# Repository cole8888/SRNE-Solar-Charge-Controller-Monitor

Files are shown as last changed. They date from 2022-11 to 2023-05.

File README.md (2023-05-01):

# SRNE-Solar-Charge-Controller-Monitor

Read data from SRNE solar charge controllers via modbus over RS232.

This repository contains several example programs for reading data from SRNE solar charge controllers using Raspberry Pi, ESP32, ESP8266 and Arduino Nano / Uno.

Based on the modbus manuals, this should also work with some Renogy controllers, but I don't have one to test with. Also, verify the wiring is compatible with your controller.

<hr>

## Example Setups:

Here are some example programs to get started. If you follow the setup instructions in the readme files of each directory, you should be able to talk to your controller. If you are just getting started, don't use the MQTT ones.

### [Raspberry Pi](./RaspberryPi-Examples/)

### [ESP32](./ESP32-Examples/)

### [ESP8266](./ESP8266-Examples/)

### [Arduino Nano / Uno](./Arduino-Example/)

<hr>

## Web-Interface and MQTT

I've included an [example web interface](./Web-Interface-Example/) you can use in combination with the MQTT-enabled example programs. To use it, you will need to setup an MQTT broker such as [Mosquitto](https://github.com/eclipse/mosquitto) or use a cloud broker. You will also need to set all the appropriate settings in the chosen program and the [index.js](./Web-Interface-Example/index.js) file.

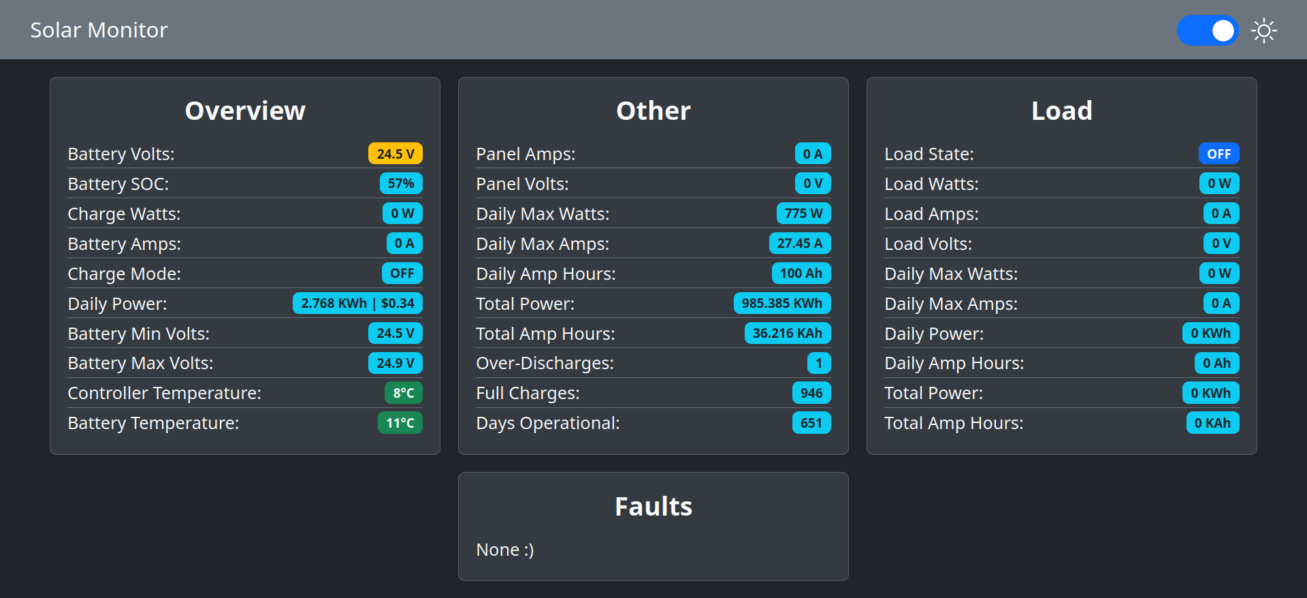
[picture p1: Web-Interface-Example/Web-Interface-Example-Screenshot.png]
Web-Interface-Screenshot


I also included my [custom web interface](./My-Current-Setup/Web-Interface/) which I am using for my setup. It has the ability to read data from and control smart plugs flashed with Tasmota.

<hr>

## My Current Setup:

The setup I use is a customized version of the ESP32 Example, I also designed a custom PCB. Have a look at [My-Current-Setup](./My-Current-Setup) if you want some inspiration for your own setup!

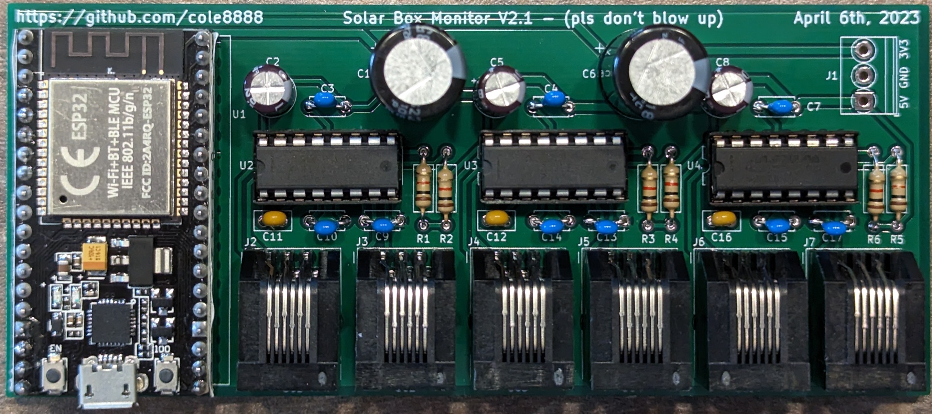
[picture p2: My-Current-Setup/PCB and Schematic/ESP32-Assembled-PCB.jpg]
ESP32 PCB Image


<hr>

## Troubleshooting:

If you notice lots of timeouts, or other errors, try some these steps before creating an issue:

- Try a different power supply and USB cable. My ML2440 does not respond when I use one of my USB power bricks, but it does with another.
- Try increasing the modbus timeout value.
- Try using a shorter cables and moving them away from interference.
- Verify you are using straight cables and not ones that reverse from one end to the other.
- Try using HardwareSerial instead of SoftwareSerial. I've found HardwareSerial is more reliable, configure the program to use it if you are having problems.

<b>If these don't help or if you need clarification, feel free to create an issue and I'll see what I can do!</b>

<hr>

## Other notes:

- I've included the [SRNE modbus manual](./SRNE-MODBUS.pdf) if you want to have a look at it. My examples read all the registers I think are important, but there are lots of other registers which I haven't touched. Be careful, some of them can be written to!

- The Python version was originally based on: http://vcsco.com/uncategorized/renogy-rover-monitoring-with-the-raspberry-pi/

- The Web-Interface was originally based on: https://github.com/fabaff/mqtt-panel

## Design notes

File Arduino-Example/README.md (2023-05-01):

# Arduino Version

This is an example sketch which uses an Arduino nano and can be adapted to an Arduino Uno. Once you get this working and want to have a go at doing more with the data, have a look at [my setup](../My-Current-Setup/) for inspiration!

Please note that there is no MQTT-enabled Arduino version as these boards have no integrated way of communicating the data over the network like the RaspberryPi and ESP modules do.

## Libraries

The libraries this project uses are:

- https://github.com/4-20ma/ModbusMaster
- https://github.com/bblanchon/ArduinoJson

## Hardware

- 1 x Arduino Nano or Arduino Uno
- 1 x RS232 transceiver module. Ex: [MAX3232 Module](https://www.digikey.ca/en/products/detail/mikroelektronika/MIKROE-602/4495610)
- 1 x [6P6C Straight Cable](https://www.digikey.ca/en/products/detail/assmann-wsw-components/AT-S-26-6-6-B-7-R/1972588) (Double check wire colors against [6P6C-Connector.jpg](../6P6C-Connector.jpg))

## Wiring

See the schematic or other photos in this directory for details.
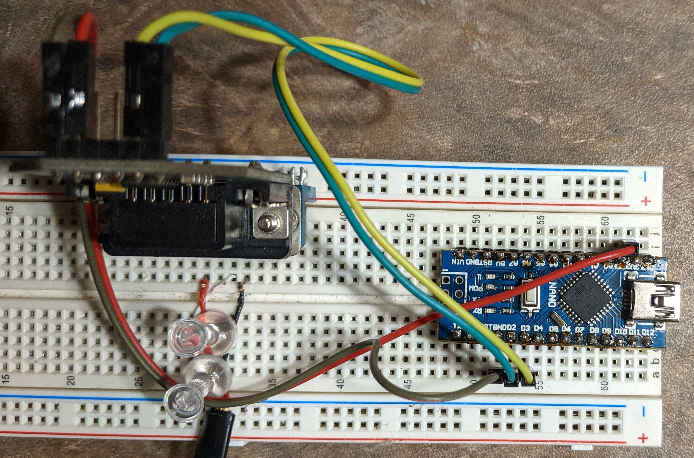
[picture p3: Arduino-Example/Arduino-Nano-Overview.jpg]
Arduino Nano Overview


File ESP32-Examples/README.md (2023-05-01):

# ESP32 Example

This is an example sketch which connects to a single charge controller so you can get started easily. Once you get this working and want to have a go at doing more with the data, have a look at [my setup](../My-Current-Setup/) for inspiration!

## Libraries

The libraries this project uses are:

- https://github.com/4-20ma/ModbusMaster
- https://github.com/bblanchon/ArduinoJson
- https://github.com/knolleary/pubsubclient (MQTT Example)

## Hardware:

- 1 x ESP32 DevKit Module
- 1 x RS232 transceiver module. Ex: [MAX3232 Module](https://www.digikey.ca/en/products/detail/mikroelektronika/MIKROE-602/4495610)
- 1 x [6P6C Straight Cable](https://www.digikey.ca/en/products/detail/assmann-wsw-components/AT-S-26-6-6-B-7-R/1972588) (Double check wire colors against [6P6C-Connector.jpg](../6P6C-Connector.jpg))

## Wiring:

Additional perspectives in the other pictures in this directory.

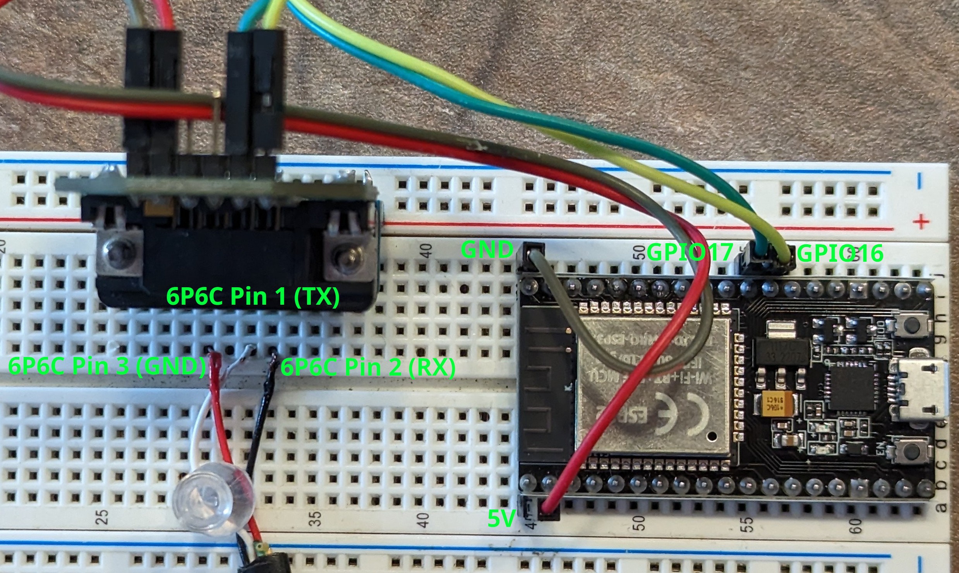
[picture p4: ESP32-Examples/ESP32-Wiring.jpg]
Wiring


## PCB

I designed a PCB which uses an ESP32 and can handle up to 6 charge controllers at once.
Have a look at it [here](../My-Current-Setup/).

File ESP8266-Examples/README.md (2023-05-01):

# ESP8266 Example
This is an example sketch which uses an ESP8266. Once you get this working and want to have a go at doing more with the data, have a look at [my setup](../My-Current-Setup/) for inspiration!

## Libraries
The libraries this project uses are:
- https://github.com/4-20ma/ModbusMaster
- https://github.com/bblanchon/ArduinoJson
- https://github.com/knolleary/pubsubclient (MQTT Example)

## Hardware:
- 1 x ESP8266 Module
- 1 x RS232 transceiver module. Ex: [MAX3232 Module](https://www.digikey.ca/en/products/detail/mikroelektronika/MIKROE-602/4495610)
- 1 x [6P6C Straight Cable](https://www.digikey.ca/en/products/detail/assmann-wsw-components/AT-S-26-6-6-B-7-R/1972588) (Double check wire colors against [6P6C-Connector.jpg](../6P6C-Connector.jpg))

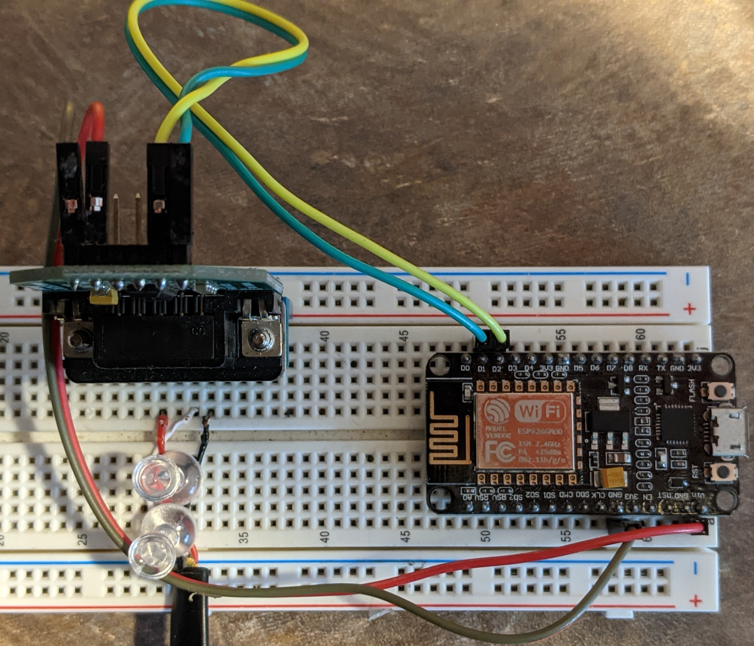
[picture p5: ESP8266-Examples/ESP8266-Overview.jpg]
ESP8266 Overview


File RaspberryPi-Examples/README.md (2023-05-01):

# Raspberry Pi Version
This example fetches the data from the controller and prints it to the console. You have the option to print it out in a text or json format.

If you encounter any issues, create an issue and I'll try to help.

## Setup:
You will need to enable serial on the raspberry pi, I used this guide: https://pimylifeup.com/raspberry-pi-serial/

You may also need to switch the serial device depending on what Pi or other device you are using.

## Libraries
- [pymodbus](https://github.com/pymodbus-dev/pymodbus)
- [paho-mqtt](https://pypi.org/project/paho-mqtt/) (Only for MQTT version)

## Hardware:
- 1 x Raspberry Pi
- 1 x RS232 transceiver module. Ex: [MAX3232 Module](https://www.digikey.ca/en/products/detail/mikroelektronika/MIKROE-602/4495610)
- 1 x [6P6C (RJ12) Straight Cable](https://www.digikey.ca/en/products/detail/assmann-wsw-components/AT-S-26-6-6-B-7-R/1972588) (Double check wire colors against [6P6C-Connector.jpg](../6P6C-Connector.jpg))

## Wiring
See other pictures for different perspectives.
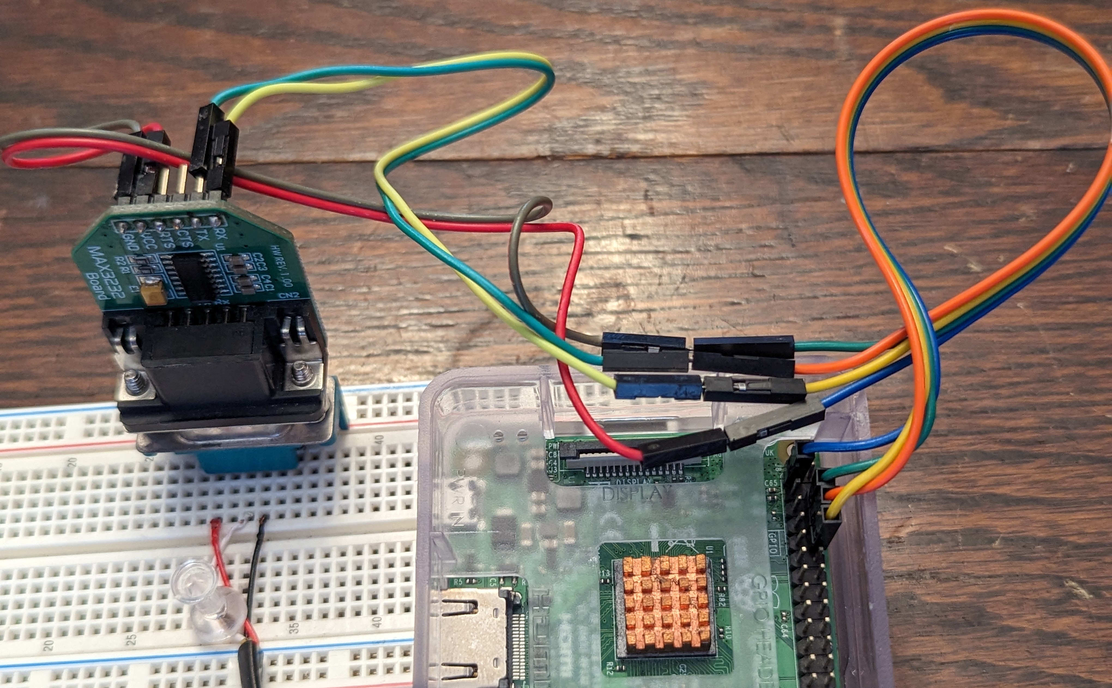
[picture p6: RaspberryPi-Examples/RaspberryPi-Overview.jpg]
RaspberryPi-Overview


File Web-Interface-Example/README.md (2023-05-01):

# Web Interface Example

This is an example web interface for viewing data returned by the example programs which publish to MQTT.

Since each of the MQTT-enabled example programs publish the data using the same JSON format, they should work out of the box assuming you specify the MQTT broker settings.



To use the interface you will need to open [index.js](./index.js) and specify the address and port of your MQTT broker along with any credentials.

This uses websockets to get the MQTT data to the browser. When configuring your broker you may need to set those up and have them run on a different port than the rest of the MQTT traffic.

<hr>

Originally based on https://github.com/fabaff/mqtt-panel

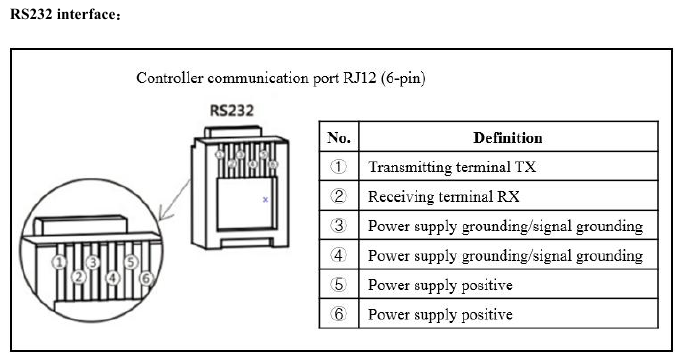
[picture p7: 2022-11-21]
Charge-Controller-Connector-Pinout.png

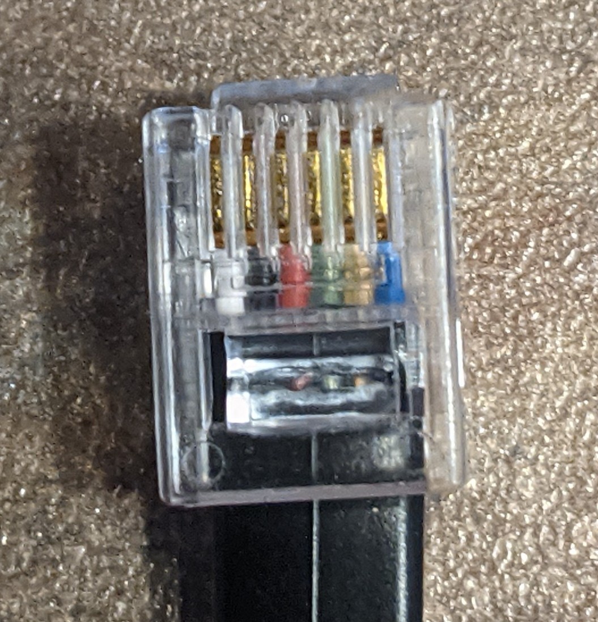
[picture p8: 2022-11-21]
6P6C-Connector.jpg

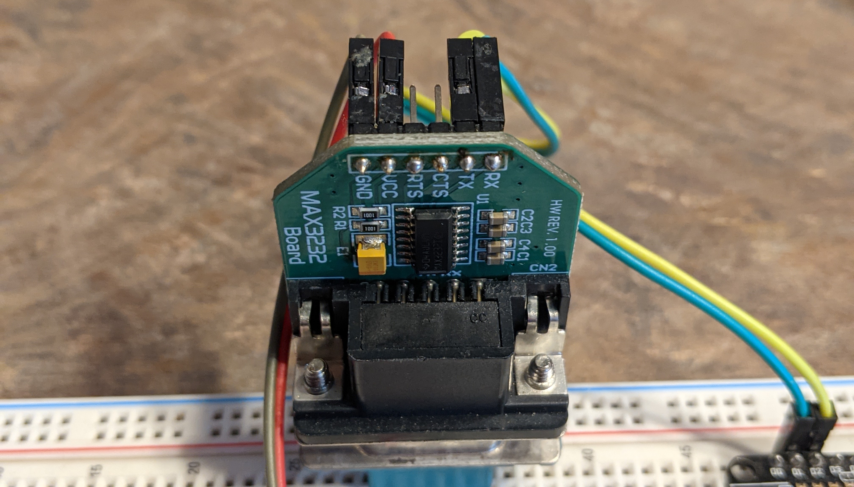
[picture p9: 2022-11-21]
Arduino-Example/MAX3232-Closeup.jpg

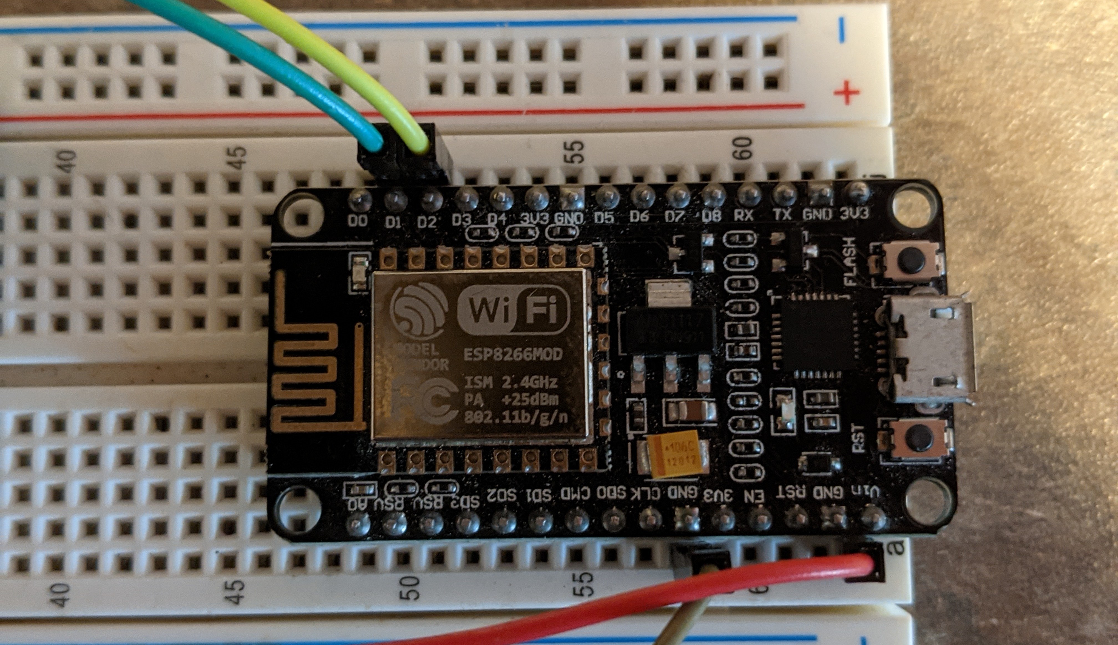
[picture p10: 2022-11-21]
ESP8266-Examples/ESP8266-Closeup.jpg

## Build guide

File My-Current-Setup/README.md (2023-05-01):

# My-Current-Setup

This is the setup I currently use. Feel free to use it for inspiration!

This version isn't intended to be plug and play like the other examples as it is specific to my needs.

## Layout

I have 3 solar charge controllers, one for the front, side, and back arrays. They feed into the ESP32 which collects the data and publishes it to an MQTT server that clients (such as the web-ui) can connect to.

I also have an ESP8266 with an LCD attached that subscribes to the MQTT feed to display some data in a convenient location around the house.

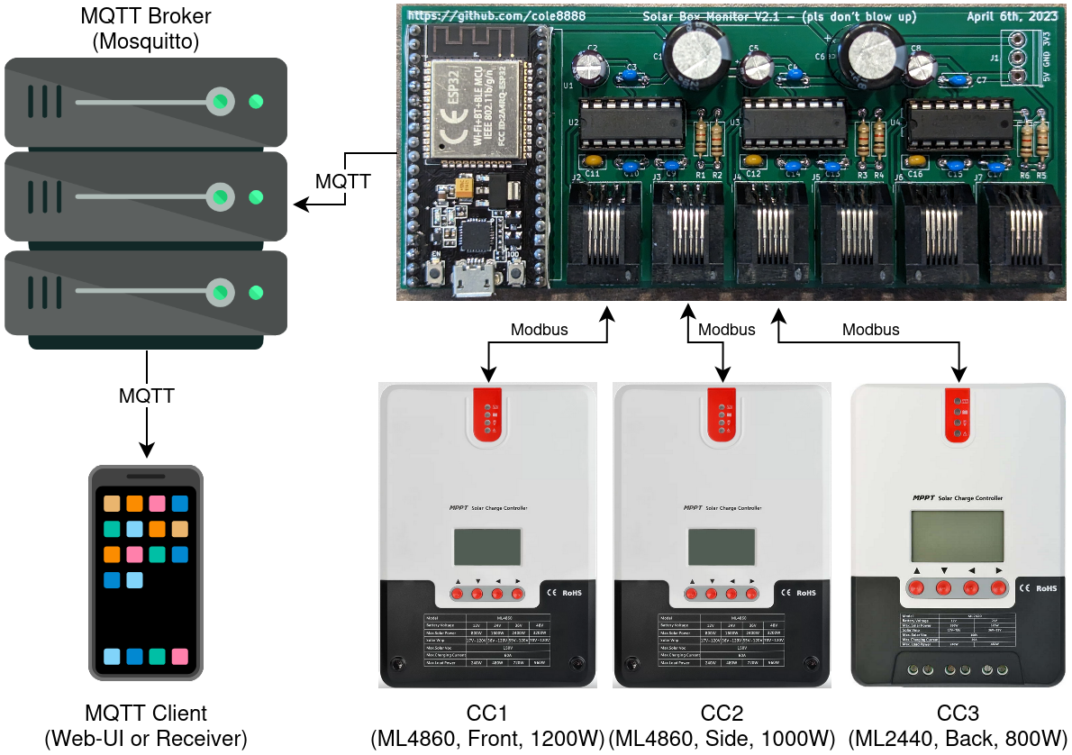
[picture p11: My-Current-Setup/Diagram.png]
Diagram


## Libraries

The libraries this project uses are:

- https://github.com/4-20ma/ModbusMaster
- https://github.com/bblanchon/ArduinoJson
- https://github.com/knolleary/pubsubclient
- https://github.com/plerup/espsoftwareserial/ (Optional, needed for >2 controllers)
- https://github.com/ayushsharma82/AsyncElegantOTA (Optional, Over the air updates)
- https://github.com/ayushsharma82/WebSerial (Optional, Over the air debugging)
- https://github.com/me-no-dev/ESPAsyncWebServer/ (Dependency of OTA and WebSerial)
- https://github.com/me-no-dev/AsyncTCP/ (Dependency of OTA and WebSerial)
- https://github.com/fdebrabander/Arduino-LiquidCrystal-I2C-library (Optional, for receiver)

## Hardware

### PCB

I designed a custom PCB for this, have a look at the [PCB files and schematic](./PCB%20and%20Schematic/).

Each PCB can handle up to 6 charge controllers at once!

PCB

NOTE: If you do plan to use my PCB, make sure you verify the footprint of the ESP32 you plan to use. The ones I have are a bit narrower than most, so you may need to adjust the footprint.

### Components:

This list is for a fully populated PCB, you may not need everything here, see schematic for details.

- 1 x [ESP32 DevKit Narrow](https://www.amazon.ca/gp/product/B07QCP2451/) (Unless you adjusted the PCB footprint yourself)
- 3 x [MAX3232](https://www.digikey.ca/en/products/detail/analog-devices-inc-maxim-integrated/MAX3232EEPE/1512691) (Or equivalent)
- 3 x [10uF Capacitor](https://www.digikey.ca/en/products/detail/nichicon/ULD2A100MED1TD/7365013)
- 9 x [0.47uF Capacitor](https://www.digikey.ca/en/products/detail/tdk-corporation/FG28X7R1H474KRT06/5803214)
- 3 x [0.1uF Capacitor](https://www.digikey.ca/en/products/detail/vishay-beyschlag-draloric-bc-components/K104K15X7RF5TL2/286538)
- 6 x [1kOhm Resistor](https://www.digikey.ca/en/products/detail/stackpole-electronics-inc/CF14JT1K00/1741314)
- 6 x [6P6C Jack](https://www.digikey.ca/en/products/detail/amphenol-cs-commercial-products/RJE031660110/4889694)
- 6 x [6P6C Straight Cable](https://www.digikey.ca/en/products/detail/assmann-wsw-components/AT-S-26-6-6-B-7-R/1972588)
- 2 x [1000uF Capacitor](https://www.digikey.ca/en/products/detail/rubycon/35ZLH1000MEFC12-5X20/3564067) (Recommended)
- 2 x [19 Position Female Header](https://www.digikey.ca/en/products/detail/sullins-connector-solutions/PPTC191LFBN-RC/810157) (Recommended, for ESP32)
- 3 x [16 Pin Dip Socket](https://www.digikey.ca/en/products/detail/amphenol-cs-fci/DILB16P-223TLF/4292068) (Recommended, for MAX3232)
- 1 x [3 position screw terminal](https://www.digikey.ca/en/products/detail/phoenix-contact/1984620/950850) (Optional)

## Web Interface

This is a customized version of the [example web interface](../Web-Interface-Example/). It has a different layout since I needed to display data from 3 charge controllers while also having smart plug controls.

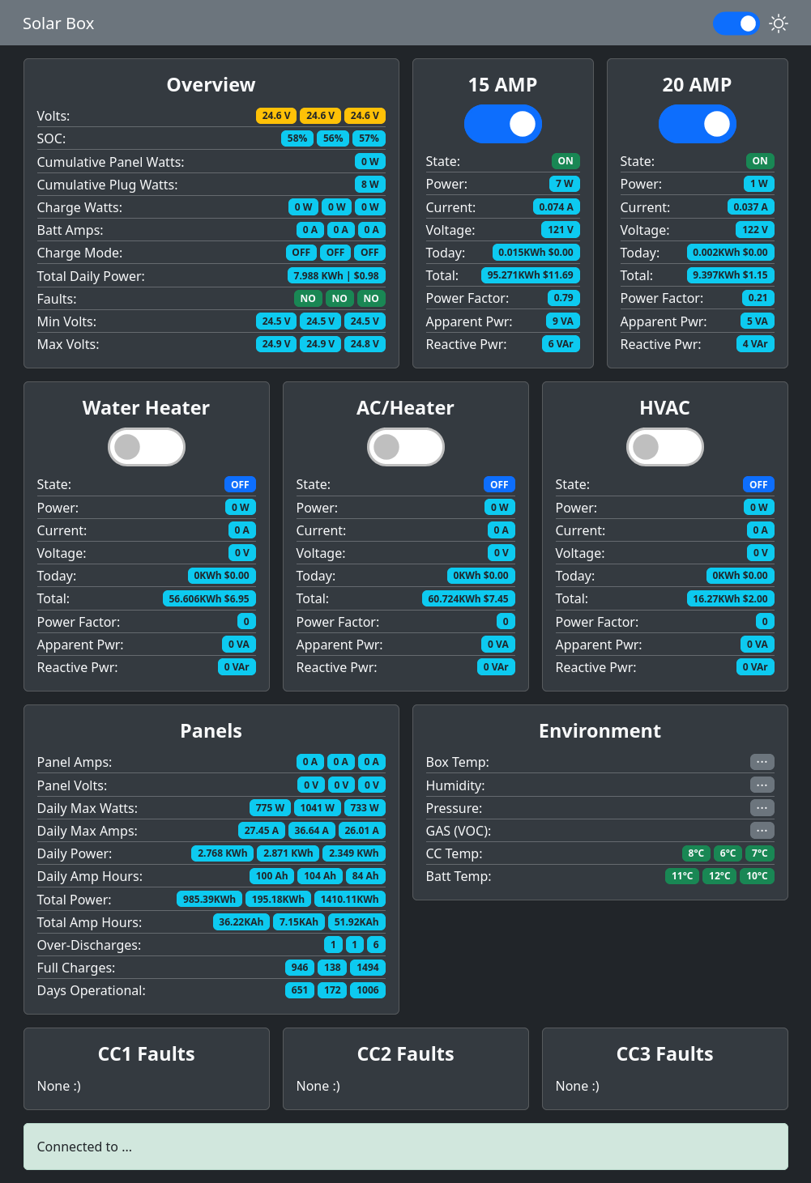
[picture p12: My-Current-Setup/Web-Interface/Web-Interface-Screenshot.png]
Web-Interface-Screenshot


<hr>

- The Web interface was originally based on https://github.com/fabaff/mqtt-panel
- Server icon in diagram is from [Roundicons](https://www.flaticon.com/free-icons/server).

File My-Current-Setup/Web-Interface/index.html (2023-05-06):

#### Overview

###### Volts: ⋅⋅⋅ ⋅⋅⋅ ⋅⋅⋅

###### SOC: ⋅⋅⋅ ⋅⋅⋅ ⋅⋅⋅

###### Cumulative Panel Watts: ⋅⋅⋅

###### Cumulative Plug Watts: ⋅⋅⋅

###### Charge Watts: ⋅⋅⋅ ⋅⋅⋅ ⋅⋅⋅

###### Batt Amps: ⋅⋅⋅ ⋅⋅⋅ ⋅⋅⋅

###### Charge Mode: ⋅⋅⋅ ⋅⋅⋅ ⋅⋅⋅

###### Total Daily Power: ⋅⋅⋅

###### Faults: ⋅⋅⋅ ⋅⋅⋅ ⋅⋅⋅

###### Min Volts: ⋅⋅⋅ ⋅⋅⋅ ⋅⋅⋅

###### Max Volts: ⋅⋅⋅ ⋅⋅⋅ ⋅⋅⋅

#### 15 AMP (http://192.168.2.131)

# Are you sure?

Are you sure you want to turn off the 15 AMP Plug?

Cancel Yes

###### State:⋅⋅⋅

###### Power: ⋅⋅⋅

###### Current: ⋅⋅⋅

###### Voltage: ⋅⋅⋅

###### Today: ⋅⋅⋅

###### Total: ⋅⋅⋅

###### Power Factor: ⋅⋅⋅

###### Apparent Pwr: ⋅⋅⋅

###### Reactive Pwr: ⋅⋅⋅

#### 20 AMP (http://192.168.2.107)

# Are you sure?

Are you sure you want to turn off the 20 AMP Plug?

Cancel Yes

###### State:⋅⋅⋅

###### Power: ⋅⋅⋅

###### Current: ⋅⋅⋅

###### Voltage: ⋅⋅⋅

###### Today: ⋅⋅⋅

###### Total: ⋅⋅⋅

###### Power Factor: ⋅⋅⋅

###### Apparent Pwr: ⋅⋅⋅

###### Reactive Pwr: ⋅⋅⋅

#### Water Heater (http://192.168.2.118)

###### State:⋅⋅⋅

###### Power: ⋅⋅⋅

###### Current: ⋅⋅⋅

###### Voltage: ⋅⋅⋅

###### Today: ⋅⋅⋅

###### Total: ⋅⋅⋅

###### Power Factor: ⋅⋅⋅

###### Apparent Pwr: ⋅⋅⋅

###### Reactive Pwr: ⋅⋅⋅

#### AC/Heater (http://192.168.2.119)

###### State:⋅⋅⋅

###### Power: ⋅⋅⋅

###### Current: ⋅⋅⋅

###### Voltage: ⋅⋅⋅

###### Today: ⋅⋅⋅

###### Total: ⋅⋅⋅

###### Power Factor: ⋅⋅⋅

###### Apparent Pwr: ⋅⋅⋅

###### Reactive Pwr: ⋅⋅⋅

#### HVAC (http://192.168.2.176)

###### State:⋅⋅⋅

###### Power: ⋅⋅⋅

###### Current: ⋅⋅⋅

###### Voltage: ⋅⋅⋅

###### Today: ⋅⋅⋅

###### Total: ⋅⋅⋅

###### Power Factor: ⋅⋅⋅

###### Apparent Pwr: ⋅⋅⋅

###### Reactive Pwr: ⋅⋅⋅

#### Panels

###### Panel Amps: ⋅⋅⋅ ⋅⋅⋅ ⋅⋅⋅

###### Panel Volts: ⋅⋅⋅ ⋅⋅⋅ ⋅⋅⋅

###### Daily Max Watts: ⋅⋅⋅ ⋅⋅⋅ ⋅⋅⋅

###### Daily Max Amps: ⋅⋅⋅ ⋅⋅⋅ ⋅⋅⋅

###### Daily Power: ⋅⋅⋅ ⋅⋅⋅ ⋅⋅⋅

###### Daily Amp Hours: ⋅⋅⋅ ⋅⋅⋅ ⋅⋅⋅

###### Total Power: ⋅⋅⋅ ⋅⋅⋅ ⋅⋅⋅

###### Total Amp Hours: ⋅⋅⋅ ⋅⋅⋅ ⋅⋅⋅

###### Over-Discharges: ⋅⋅⋅ ⋅⋅⋅ ⋅⋅⋅

###### Full Charges: ⋅⋅⋅ ⋅⋅⋅ ⋅⋅⋅

###### Days Operational: ⋅⋅⋅ ⋅⋅⋅ ⋅⋅⋅

#### Environment

###### Box Temp: ⋅⋅⋅

###### Humidity: ⋅⋅⋅

###### Pressure: ⋅⋅⋅

###### GAS (VOC): ⋅⋅⋅

###### CC Temp: ⋅⋅⋅ ⋅⋅⋅ ⋅⋅⋅

###### Batt Temp: ⋅⋅⋅ ⋅⋅⋅ ⋅⋅⋅

#### CC1 Faults

###### None :)

#### CC2 Faults

###### None :)

#### CC3 Faults

###### None :)

Loading...

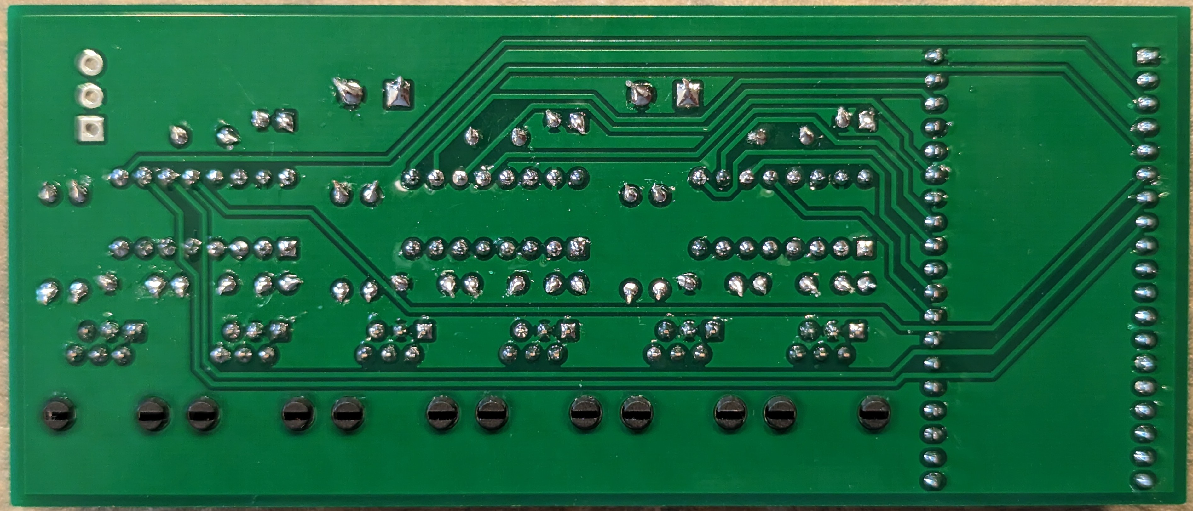
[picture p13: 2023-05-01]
My-Current-Setup/PCB and Schematic/ESP32-Assembled-PCB-Back.jpg

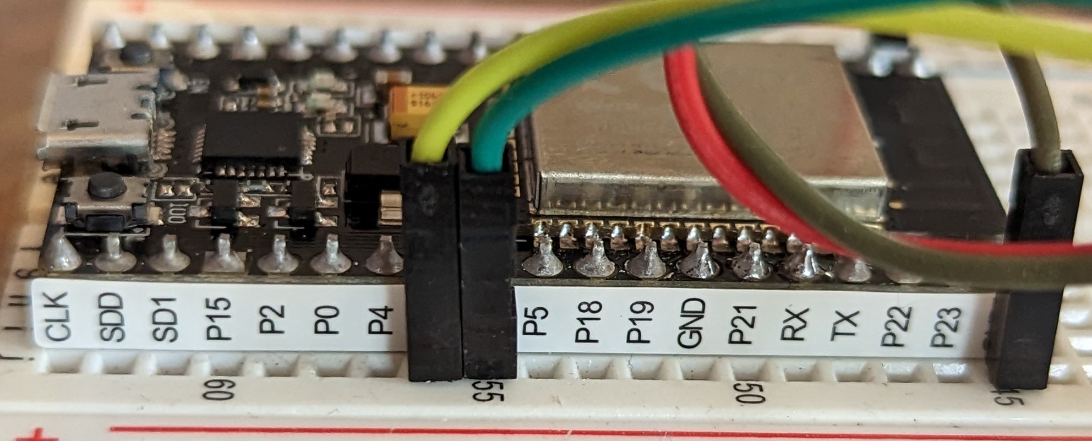
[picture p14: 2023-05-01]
ESP32-Examples/ESP32-Wiring-Side.jpg

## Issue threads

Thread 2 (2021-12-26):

<0°C temperatures dont work.

cole8888, 2021-12-26:
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

Something is wonky with the temperature readouts when the temperature gets to <0.

Was not able to test this at the time I wrote this program because it was summer time.

I have only checked the Arduino version, I'm not sure if the python version also has this problem, but I assume it does.

Closed 2022-10-08.

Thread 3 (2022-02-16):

[QUESTION]

curiousIya, 2022-02-16:
Hi! Thank you so much for your python code :) I'm using it to read my ML4860 Solar Controller.
I removed the mqtt and the CC1 lines.

Just some questions,
How do you know how many registers to read?
And which registers refers to a value (eg r.registers[7] is Panel Voltage)?
Also, whose temperature do you refer in CPUTemperature().temperature? the raspberry pi?

cole8888, 2022-02-16:
You can determine which register corresponds to which value using the modbus manual I included here: https://github.com/cole8888/SRNE-Solar-Charge-Controller-Monitor/blob/main/srne_modbus_protocol-_3.8-english.pdf

For instance, at the start of the "Controller dynamic information" section you can see 0100H (100 in hexadecimal, 256 in decimal) is the battery state of charge percentage.

As for the number of registers, the reason I read 34 registers in my code is because that is the end of the "Controller dynamic information" section (122H) and beyond this address you start getting into the memory for the controller settings, which I was not interested in.

So if you only ever wanted to read the battery state of charge percentage and the battery voltage and nothing else, you could change that 34 to 2 since you'd only need to be reading registers 100H and 101H. If I were you I'd leave it at 34 though since that way it returns all the information you could possibly need.

Also, yes the CPU temperature was for the raspberry pi. The deck box I use can get pretty toasty and I wanted to make sure I wasn't cooking it :P

curiousIya, 2022-02-16:
Thank you very much! :)

To check if there is error, should I read r.registers[33] and r.registers[34]?

Also, do you know how to write register/enable load?

cole8888, 2022-02-17:
By error I assume you mean faults reported by the controller such as shorts and low battery warnings?

After looking though the Arduino code again and the manual, I think you only have to read register 34 (aka 122H in the manual) since the error data is only stored in the higher bits and bits 0-15 are reserved. I'm pretty sure my python code is wrong since it reads register 33 instead of 34 (or 121H instead of 122H). In this case you may need to increase the 34 in
```r = modbus.read_holding_registers(256, 34, unit=1)``` to a 35 and use r.registers[34] to get the fault codes. Upon closer inspection it looks like I fixed this in the arduino code and forgot to update the python code with this fix.

As for extracting the fault codes from the data in this register, the raspberry pi or arduino code doesn't have any code for this because I handled it on the web interface viewer I made.

I had an array of fault strings (order and index is important!):
```
faultCodes[
    "Charge MOS short circuit",     //0
    "Anti-reverse MOS short",       //1
    "PV panel reversely connected", //2
    "PV working point over voltage",//3
    "PV counter current",           //4
    "PV input side over-voltage",   //5
    "PV input side short circuit",  //6
    "PV input overpower",           //7
    "Ambient temp too high",        //8
    "Controller temp too high",     //9
    "Load over-power/current",      //10
    "Load short circuit",           //11
    "Battery undervoltage warning", //12
    "Battery overvoltage",          //13
    "Battery over-discharge"];      //14
```
And here is the code I used for parsing the register data and making a string that contains the current errors:
```
  var faults = "None :)";
  if(faultID != 0){
      faults = "";
      var count = 0;
      while(faultID != 0){
          if(faultID >= Math.pow(2, 15-count)){
              // If there is more than one error, make a new line.
              if(count > 0){
                  faults += '<br>';
              }
              faults += '- ' + faultCodes[count-1];
              faultID -= Math.pow(2, 15-count);
          }
          count += 1;
      }
  }
```
(where faultID is the r.registers[34] data)
This is from a javascript program so you will need to adapt it to python for your use case. Let me know if you need any help with that. Essentially what I do is repeatedly check to see if I can subtract a power of two, and if I can then I know which bit it is and therefore which error(s) are present.

The deck box where I keep my charge controllers is not easily accessible during the winter so I cannot hook up my raspberry pi to test anything I've said here, so let me know if you encounter any issues.

Closed 2022-11-25.

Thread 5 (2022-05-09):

Very high VOC resistance readings cause display to glitch out and esp8266 to crash.

cole8888, 2022-05-09:
I think something is wonky with my sensor since I've never seen values that high, but this shouldn't happen regardless. It initially caused the esp8266 to crash completely when it first happened and on reboot it had the resistance symbol at the start of the second row instead of being at the end of the third.

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

cole8888, 2022-05-11:
Addressed in ee20e3747f064618f7e9fd9809d60bffbe23b393

Closed 2022-05-11.

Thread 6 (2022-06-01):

Publishing data

Shadow-Genesis, 2022-06-01:
I'm using the Python version, I was getting a bunch of errors and code crashing from the mqtt. I read your description of the project and saw that it send the data off to another device. I don't have it setup with a second device., so maybe an error due to me not having it setup that way.

`Traceback (most recent call last):
  File "/home/USER/SolarComms/SRNE.py", line 82, in <module>
    client = connect_mqtt()
  File "/home/USER/SolarComms/SRNE.py", line 73, in connect_mqtt
    client.connect(broker, port)
  File "/usr/local/lib/python3.9/dist-packages/paho/mqtt/client.py", line 914, in connect
    return self.reconnect()
  File "/usr/local/lib/python3.9/dist-packages/paho/mqtt/client.py", line 1044, in reconnect
    sock = self._create_socket_connection()
  File "/usr/local/lib/python3.9/dist-packages/paho/mqtt/client.py", line 3685, in _create_socket_connection
    return socket.create_connection(addr, timeout=self._connect_timeout, source_address=source)
  File "/usr/lib/python3.9/socket.py", line 843, in create_connection
    raise err
  File "/usr/lib/python3.9/socket.py", line 831, in create_connection
    sock.connect(sa)
ConnectionRefusedError: [Errno 111] Connection refused`

Also, thank you! I was about to pull my hair out trying to get it to work.

Closed 2022-11-25.

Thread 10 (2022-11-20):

1 Arduino only

Rey1635, 2022-11-20:
As a newbie, I would like to ask how to use only 1 arduino to read the battery voltage and the charging state status of the SRNE? How will I connect it to arduino? Thank you very much for your help.

cole8888, 2022-11-20:
Hi, sorry about not thinking about that, I'll make a schematic / code for a single arduino and charge controller.
Will you have access to an esp8266? I'm thinking i can get it to work with just one esp8266. That way you don't have to deal with the RF24 stuff.

Rey1635, 2022-11-20:
Thank you very much for your response.. I do have an esp8266. I'll just wait for your update.  God Bless You always.

cole8888, 2022-11-20:
You are also going to need a MAX3232 breakout board since the voltage level the charge controller uses to talk over rs232 isn't compatible with the Arduino and needs to be converted.

I found [this](https://www.amazon.com/Treedix-MAX3232-Convert-Transceiver-Breakout/dp/B09BCKWL8V) on amazon and it should work.

I'm not sure where you are from but try searching for "MAX3232 breakout" and see if you can find something simmilar to that, feel free to send links to the ones you find and I can try to tell you if they will work.

If you can only find ones which look like [this](https://www.amazon.com/NOYITO-Module-Conversion-Arduino-communicates/dp/B07BJJC3R6/) that's ok, you'll need to find a way to connect to the DB9 connector using something like [this](https://www.amazon.com/Connector-Female-Adapter-Terminal-Signal/dp/B086VYDPKH/).

cole8888, 2022-11-20:
I managed to get a ESP8266 to talk to the charge controller, will upload code, schematic and pictures shortly.

Rey1635, 2022-11-20:
I do have one of [this](https://www.amazon.com/HiLetgo-Level-Converter-Board-Rs232/dp/B00LUDCAXQ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) and I already have a RJ12 (6P6C).  Thank you very much

cole8888, 2022-11-21:
Nice, that should work!

I uploaded some examples and much more detailed instructions, have a look at them [here](https://github.com/cole8888/SRNE-Solar-Charge-Controller-Monitor/tree/main/Arduino-Version).

Also [this particular example](https://github.com/cole8888/SRNE-Solar-Charge-Controller-Monitor/blob/main/Arduino-Version/Single-Charge-Controller/SOLAR_SINGLE_CC/SOLAR_SINGLE_CC.ino) is the one you are interested in, just make sure you replace the `MAX3232_RX` and `MAX3232_TX` values to whatever pins you are using.

Let me know if you run into any problems :)

Rey1635, 2022-11-21:
Thank you very much.  I'm so excited to start my project.  May God Bless You always.

Rey1635, 2022-11-21:
I tried to the upload code on my esp8266 but there is an error ("'class Modbus' has no member named 'start'") on master.start(); I've already  installed the modbus-esp8266 library.

cole8888, 2022-11-21:
I'm not using that modbus library, I used https://github.com/smarmengol/Modbus-Master-Slave-for-Arduino
There are instructions in that repoitory for how to install it, I don't think it is in the Arduino IDE.

Rey1635, 2022-11-21:
thanks for the link of the library.. error has been solved.

Rey1635, 2022-11-21:
Sad to say no luck for me.. I have already tried with arduino.
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

Rey1635, 2022-11-21:
Maybe I should purchase a different type of  MAX3232 breakout board.

cole8888, 2022-11-21:
How do you have it wired up? You may have RX and TX backwards on either the arduino side or the charge controller side.

Rey1635, 2022-11-22:
Here is how  I wired up.
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

cole8888, 2022-11-22:
On the arduino side the you have the VCC and GND reversed. Also I'm not sure what roles you have assigned to D2 and D3. For getting it started for the first time, can you stick to D1 and D2 since those are the only pins I tested.
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
Your RX and TX lines seem correct though.

cole8888, 2022-11-22:
I'm pretty sure D3 cannot be used for software serial according to some stuff I found online. Just use D1 and D2 for now since I know those work.

Rey1635, 2022-11-22:
Thank you very much.

cole8888, 2022-11-22:
Were you able to get it to work?

I have Arduino nano wiring examples [here](https://github.com/cole8888/SRNE-Solar-Charge-Controller-Monitor/tree/main/Arduino-Version/Single-Charge-Controller/Photos%20and%20Schematics).
So, if you follow those examples use:
`#define MAX3232_RX 2`
`#define MAX3232_TX 3`

Rey1635, 2022-11-22:
still no luck.  I will  just purchase other type of MAX3232 breakout.

cole8888, 2022-11-22:
Darn.

Here is the one i use by the way: https://www.digikey.com/en/products/detail/mikroelektronika/MIKROE-602/4495610

cole8888, 2022-11-22:
Also which charge controller are you using?

Rey1635, 2022-11-22:
I'm using SRNE ML2420

cole8888, 2022-11-22:
Yeah that should work, appears to be nearly identical to the ML2440 which is one of the ones I use and the manual says it supports modbus and the bluetooth module which means we should be able to talk to it since the bluetooth module is pretty much doing the same thing.

If you do get one of the ones with the DB9 connector (like the one I used) make sure you get a DB9 breakout adapter like [this](https://www.amazon.com/Connector-Adapter-Terminal-Signal-Module/dp/B071DS5GTW).

Rey1635, 2022-11-22:
ok. thanks for the suggestion, I'll do get that one.

Shadow-Genesis, 2022-11-22:
I know I maybe a little late on saying this. But to the serial board, I just found a USB cable for it. It is USB-A to RS232 Serial 6P6C on Amazon. I use a Raspberry PI for mine so USB works for me, and my work for others.

[https://www.amazon.com/dp/B07JGRJR4V?psc=1&ref=ppx_yo2ov_dt_b_product_details](url)

Rey1635, 2022-11-30:
Good day, I would like to ask if my connections are correct.
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
 and I changed the arduino code with this..
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

 Thank you very much

Rey1635, 2022-11-30:
Here's mine..
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

Rey1635, 2022-11-30:
Here's mine..
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

Rey1635, 2022-11-30:
changed the code
#define MAX3232_RX D1 // RX pin. If following my ESP8266 instructions use D1.
#define MAX3232_TX D2 // TX pin. If following my ESP8266 instructions use D2.

but  'D1' was not declared in this scope

cole8888, 2022-11-30:
Interesting, seems like some ESP8266 do not support the D labels. Lets just use the pin numbers directly.
```
#define MAX3232_RX 5 // RX pin. If following my ESP8266 instructions use D1.
#define MAX3232_TX 4 // TX pin. If following my ESP8266 instructions use D2.
```

cole8888, 2022-11-30:
Here is your diagram with the colors from your cable.
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

Rey1635, 2022-12-05:
Still no luck even with new arduino nano...  I followed your given pictures..
#define MAX3232_RX 2
#define MAX3232_TX 3

cole8888, 2022-12-05:
The MAX3232 board has the same pinout as mine and the breakout should eliminate contact issues.

For the ground (Green on RJ12) are you using the GND terminal block on the breakout connector? If so can you switch to using pin 5 instead? It looks like some of these breakouts don't actually connect that terminal to pin 5.

Also just to clarify BLUE->3, YELLOW->2, GREEN->5

Rey1635, 2022-12-05:
I'm using pin 5 as ground on  breakout connector. also blue to pin 3, yellow to pin 2 and green to 5.  I will try reboot my charge controller
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
Rey1635, 2022-12-08:
Library used is https://github.com/syvic/ModbusMaster.
Here is my serial output..
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
and the charge controller display..
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

Rey1635, 2022-12-08:
I found the code from here https://forum.arduino.cc/t/trying-to-read-registers-from-a-solar-charge-controller-over-rs232-solved/1039864/11

cole8888, 2022-12-08:
Hey can you include the data registers too? That's where the information you want is.

Rey1635, 2022-12-08:
Sorry, cant understand what data register is, I just copied the code from here https://forum.arduino.cc/t/trying-to-read-registers-from-a-solar-charge-controller-over-rs232-solved/1039864/11 and upload it to esp32

cole8888, 2022-12-08:
In the console output that script prints out two sets of data, one of them is called info registers and one is data registers. The data registers are the ones we want. There should be a header with the text "Successfully read the data registers!" printed above them.
Also could you send a picture of how you wired up the the ESP32? I'm trying to see if changing the modbus address will make my code work.

Rey1635, 2022-12-08:
console output for first set..
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

I just followed this..
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

cole8888, 2022-12-08:
Their TX and RX in the diagram seem to be opposite to mine so I just wanted to see how you physically hooked it up so I could assign the correct pin numbers in my code for you to try out.

cole8888, 2022-12-08:
An updated picture like this would be awesome: https://github.com/cole8888/SRNE-Solar-Charge-Controller-Monitor/issues/10#issuecomment-1338694262

Rey1635, 2022-12-08:
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

cole8888, 2022-12-08:
This data seems to be in the exact same format as what my program is expecting.

In the program we were working with previously can you try these settings?
`
#define MAX3232_RX 17
#define MAX3232_TX 16
`
and
`
#define MODBUS_SLAVE_ADDR 255
`

Rey1635, 2022-12-08:
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

cole8888, 2022-12-08:
Shoot I got it backwards, try:
```
#define MAX3232_RX 16
#define MAX3232_TX 17
```
instead please.

Rey1635, 2022-12-08:
error SoftwareSerial.h: No such file or directory

Rey1635, 2022-12-08:
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

cole8888, 2022-12-08:
Damnit, I'll jerry rig something quick which should let you access the information on your ESP32, just give me a minute.

cole8888, 2022-12-08:
WAIT, you have D1 and D2 cables backwards!

Rey1635, 2022-12-08:
green to D!, purple to D2 is still no luck.. and with this connection the COM icon in charge controller does not a appear but if purple to D1 and green to D2 the COM icon in charge controller appears..

cole8888, 2022-12-08:
That is bizarre. If the COM icon appears it is making a connection though.
It's too late for me to keep going but let me know if this displays the stuff you want. Tomorrow I can try and get the rest of the information out of it.
I couldn't compile this because I don't know what ESP32 you are using and I kept getting library issues so let me know if there is a problem.
[solar.zip](https://github.com/cole8888/SRNE-Solar-Charge-Controller-Monitor/files/10183033/solar.zip)

Rey1635, 2022-12-08:
ok.. Thank you

Rey1635, 2022-12-08:
ok.. Thank you

cole8888, 2022-12-09:
I've dug into it a bit more and I'm pretty sure I found what is causing the problem.

The reason address 255 is working for you on that one program is because that is a special address which all controllers will respond to regardless of what their actual address is. For some reason your charge controller has an address that is not 1 unlike every other controller I've seen so far.
The library in that example you provided accepts address 255 and I am able to get my controllers to respond, but using the modbus library I chose for my program it seems to not accept address 255.

I dug into the source code of the library and sure enough:
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
By manually changing both of those from 247 to 255 and restarting the Arduino IDE then re-uploading to the esp8266 I was able to get address 255 working on my program.

If you don't mind, in your Arduino libraries folder can you swap the library source code file (Modbus-Master-Slave-for-Arduino -> ModbusRTU.h) with this one https://github.com/cole8888/SRNE-Solar-Charge-Controller-Monitor/blob/test-address-fix/Arduino-Version/Single-Charge-Controller/ModbusRtu.h, then wire up your esp8266 and program it with this?
https://github.com/cole8888/SRNE-Solar-Charge-Controller-Monitor/blob/test-address-fix/Arduino-Version/Single-Charge-Controller/SOLAR_SINGLE_CC/SOLAR_SINGLE_CC.ino (I indicated which connections to make in the comments).

Rey1635, 2022-12-20:
Thank you very much! I've already got it!   God Bless & Merry Christmas!

Luisdjnas, 2023-02-20:
Hello, I have a srne 2420 and I have messed up the internal software by mistake with an app. Could someone tell me how to put the original software back??

Closed 2023-01-09.

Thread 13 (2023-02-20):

Software srne ml2420

Luisdjnas, 2023-02-20:
Hello, I tried to update the ml2420 through an app and the installation failed. Is there any way to enter the original software?

cole8888, 2023-02-21:
I'm not sure. Assuming you could get the equipment to talk to the controller, there is a command in the modbus manual for resetting the controller to factory defaults. I don't know if this will be able to fix a failed firmware update though.

I also found a manual of a different SRNE charge controller which said you could press the "select" button (rightmost button for this one maybe) for 20 seconds to reset it, I don't know if it will work with your controller though.

Does it turn on at all or does it show anything on the screen/led indicators?

If it is still under warranty you are probably better off trying to go through whoever you bought it from to get a replacement. If not then it might be best to just get a new controller.

Luisdjnas, 2023-02-21:
I've tried holding the button down and it doesn't work.  Unfortunately the seller does not cover a guarantee of what happened.  From the app it does not let you restore it to factory settings either.  The controller shows nothing on the screen but the bt-01 module turns on.  I don't know what I could do anymore.

Luisdjnas, 2023-02-24:
there is no way to enter the original software again?? I would be very grateful for a solution.

Luisdjnas, 2023-02-24:
there is no way to enter the original software again?? I would be very grateful for a solution.

cole8888, 2023-02-24:
I don't work for SRNE, I don't know.

You'll have to contact SRNE support to see if there is anything you can to do / see if they will replace it.

Luisdjnas, 2023-02-24:
I got in touch and they didn't give me any solution, I just had to buy another one. that was the problem. 😔

Luisdjnas, 2023-02-24:
I got in touch and they didn't give me any solution, I just had to buy another one. that was the problem. 😔

Closed 2023-03-10.

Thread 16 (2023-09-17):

pyModbus

Shadow-Genesis, 2023-09-17:
I was trying to use the python script for the raspberry PI to monitor my charger controller again, been without it for a long time now.

As I was setting up the script on my PI, only editing for my port/device, I ran in to error.

`Traceback (most recent call last):
  File "/home/USER/SRNE.py", line 17, in <module>
    from pymodbus.client.sync import ModbusSerialClient as ModbusClient
ModuleNotFoundError: No module named 'pymodbus.client.sync'`

FIX: Change "pymodbus.client.sync" to "pymodbus.client"

Closed 2023-11-22.

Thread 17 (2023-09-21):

Can't read data, help please.

Shadow-Genesis, 2023-09-21:
Hello I'm trying to use the python script for the raspberry pi again, used it last year it worked great. When I go to read any data from my ML2420 I get errors. I connect over a USB serial cable and I have the bluetooth adapter and it works fine.......

My code, the same other then a debug line I added.
`def run():
    if False: #I added this if as a DEBUG
        response = modbus.read_holding_registers(26, 1, unit=0)
        print(response)
    while True:
        try:
            # Read 35 registers from the controller starting at address 0x0100 (Decimal 256) until 0x0122 (Decimal 290)
            response = modbus.read_holding_registers(256, 35, unit=0)
            if(JSON_OR_TEXT == "TEXT"):
                printDataText(response)
            else:
                print(convertToJson(response, False))
            time.sleep(DELAY_BETWEEN_REQUESTS)
        except Exception as e:
            if(JSON_OR_TEXT == "TEXT"):
                print("Failed to read data, reconnecting...", e)
            else:
                print(convertToJson(None, True))
            reconnectModbus()
            time.sleep(DELAY_BETWEEN_REQUESTS)`

I get the error "Failed to read data, reconnecting... 'ModbusIOException' object has no attribute 'registers' "
And when I do my debug I get "Modbus Error: [Input/Output] Modbus Error: [Invalid Message] No response received, expected at least 4 bytes (0 received)"

I really could use the help right now.

cole8888, 2023-09-21:
Hi, sorry for the delayed response. I've been able to reproduce the problem on my PI also and I'll try to have a fix for it soon.

Shadow-Genesis, 2023-09-21:
Thank you, and wow that was fast.

cole8888, 2023-09-21:
The correct setup is Raspberry pi GPIO14 goes to MAX3232 TX and GPIO15 goes to RX

While trying to reproduce it I had the wires backwards and got the behavior you mentioned. After flipping them to be correct I was able to read data. Also what python/pymodbus version are you using?

cole8888, 2023-09-21:
I just double checked the wiring photos in that directory and they are correct.

This one is probably the easiest to compare against:
https://github.com/cole8888/SRNE-Solar-Charge-Controller-Monitor/blob/main/RaspberryPi-Examples/RaspberryPi-Top-View.jpg

Shadow-Genesis, 2023-09-22:
I'm using a USB connecter, and I did check and redo my wires. Pin 1 to my RX and pin 2 to my TX and pins 3 & 4 to ground. Pins 5 & 6 are power and not connected.

FYI: Pins 5 & 6 give off battery voltage.

Shadow-Genesis, 2023-09-22:
So I got a bit of an update. I have for my pc the Solar Station Monitor software. With it I can connect if I set the device ID to 255. Still not working with the python script. Any ideas?

cole8888, 2023-09-23:
Address 255 is a special address that all charge controllers respond to no matter what their current address is.

Your controller must have a different address than mine. Ran into a similar thing with the Arduino versions and I fixed it there by forcing address 255, but I didn't realize the python version would also have this problem.

Try replacing the line with `read_holding_registers` with this:
`response = modbus.read_holding_registers(256, 35, unit=1, slave=255)`

Shadow-Genesis, 2023-09-23:
So adding the "slave" parameters fixed it. I would like to note that the code works without the "unit" parameters and that the "slave" needs to be your device ID.

`response = modbus.read_holding_registers(256, 35, slave=1)`

Thank you for your help, hope this helps others.

cole8888, 2023-09-23:
@Shadow-Genesis Just wondering, did this work when you set slave to 255 instead of 1? If it worked with 255 I'll update the program since it should work for all controllers.

Shadow-Genesis, 2023-09-23:
Both. My device is ID 1. And from what I read in the PDF that talks about how data is sent and received, 255 is a device ID that all respond to. Mostly for use with bluetooth adapters and remote displays. So in short from what I read, the device ID 255 is a plug and play ID

cole8888, 2023-09-23:
Ok, I'll update the script to use 255, should prevent issues in the future. Thanks!

Shadow-Genesis, 2023-09-23:
I had been making since last night a python class that would handle the SRNE data, makes it cleaner for me. I just got a bit of code I think you may want to add.

`
deviceID=None
response = self.modbus.read_holding_registers(26, 1, slave=255)
deviceID = response.registers[0]
response = self.modbus.read_holding_registers(256, 35, slave=deviceID)
`

its just a little auto device ID. I do not think it would work with more then one slave connected, but for one it should be fine

Closed 2023-09-23.

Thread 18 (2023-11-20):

MobusIOException object has no attribute 'registers'

magorm, 2023-11-20:
Getting the error 'has no attribute registers' when running SolarMonitor.py. Need your help :-)

cole8888, 2023-11-21:
What charge controller are you using and how have you connected to it?

Can you try replacing the line containing `read_holding_registers` with `response = modbus.read_holding_registers(256, 35, unit=1, slave=255)`.

If your charge controller address is different than mine this will fix it.

magorm, 2023-11-21:
Thanks so much.
Here is how I connected SNRE SCC to my Laptop running the Python script:
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

magorm, 2023-11-22:
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

Did not work. I think the issue is related to USB adapter?

cole8888, 2023-11-22:
Which USB adapter are you using? It might not use the right voltage.

cole8888, 2023-11-22:
Also, can you show how you wired the serial adapter up to the RJ12 cable?

magorm, 2023-11-24:
> Which USB adapter are you using? It might not use the right voltage.

I am using this adapter: USB to TTL converter UART module CH340G CH340 3.3V 5V switch

magorm, 2023-11-24:
> Also, can you show how you wired the serial adapter up to the RJ12 cable?

![Uploading solar-monitor.png…]()

cole8888, 2023-11-24:
The CH340G won't work, it only does +/-5V where RS232 needs +/-13V.

You'll need to use a usb to RS232 converter like this one:
https://www.amazon.ca/StarTech-com-USB-Serial-Adapter-Prolific/dp/B00GRP8EZU

Also, I can't see that image so I'm not sure how you wired it up to your charge controller.

magorm, 2023-11-25:
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

Thanks.
Apologies. Here's the connection diagram.
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

magorm, 2023-11-25:
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

In your demo, you use Raspberry Pi, is the Pi serial using +-13v? Thanks in advance.

cole8888, 2023-11-25:
The Pi is not using that voltage. In my demo it has to go through a breakout board with a MAX3232 on it which handles the voltage boost to talk to the charge controller.

cole8888, 2023-11-25:
You can see it here:
https://github.com/cole8888/SRNE-Solar-Charge-Controller-Monitor/blob/main/RaspberryPi-Examples/RaspberryPi-Overview.jpg

magorm, 2023-11-25:
> MAX3232

Thanks. Will try this board, see if it will work - https://shopee.ph/MAX3232-RS232-to-TTL-Serial-Port-Converter-Module-DB9-Connector-MAX232-For-Arduino-i.226548939.4317808086

magorm, 2023-12-06:
Not yet. I already setup the raspberry pi zero 2w, made the code run but I think I bought a wrong RS232 adapter. I already ordered the board (https://www.digikey.ph/en/products/detail/mikroelektronika/MIKROE-602/4495610) similar to what you used. Hopefully I can make it work.

magorm, 2023-12-06:
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

magorm, 2023-12-08:
Hi. How did you get the register address? In the code its 256, not sure if it the same with SRNE charge controller?

magorm, 2023-12-09:
> I'm using SRNE charge controllers, which ones are you using?
>
> I got it from the SRNE modbus datasheet

Thanks. I am using the same SCC.

cole8888, 2023-12-09:
I have that one also, so you definitely should be able to get it to work with it :)

magorm, 2023-12-09:
> I have that one also, so you definitely should be able to get it to work with it :)

In rj12, did you use pin1 (tx), pin2 (rx) and pin3(gnd)? pin4 is also gnd but not sure if I should use it instead of pin3?

cole8888, 2023-12-09:
It should work either way. I only used pin 3 for ground.

magorm, 2023-12-11:
Hi @cole8888 , for RJ12, the pin 1 is from the left side, right?

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

magorm, 2023-12-11:
This is the log when I run the script; it is sending  0xff 0x3 0x1 0x0 0x0 0x23 0x10 0x31?
Connection : True
DEBUG:pymodbus.logging:Current transaction state - IDLE
DEBUG:pymodbus.logging:Running transaction 1
DEBUG:pymodbus.logging:SEND: 0xff 0x3 0x1 0x0 0x0 0x23 0x10 0x31
DEBUG:pymodbus.logging:New Transaction state "SENDING"
WARNING:pymodbus.logging:Cleanup recv buffer before send: 0x0 0x0 0x0
DEBUG:pymodbus.logging:Changing transaction state from "SENDING" to "WAITING FOR REPLY"
DEBUG:pymodbus.logging:Changing transaction state from "WAITING FOR REPLY" to "PROCESSING REPLY"
DEBUG:pymodbus.logging:RECV: 0x0 0x0 0x0 0x0 0x0 0x0 0x0 0x0 0x0 0x0 0x0 0x0 0x0 0x0 0x0 0x0 0x0 0x0 0x0 0x0 0x0 0x0 0x0 0x0 0x0 0x0 0x0 0x0 0x0 0x0 0x0 0x0 0x0 0x0 0x0 0x0 0x0 0x0 0x0 0x0 0x0 0x0 0x0 0x0 0x0 0x0 0x0 0x0 0x0 0x0 0x0 0x0 0x0 0x0 0x0 0x0 0x0 0x0 0x0 0x0 0x0 0x0 0x0 0x0 0x0 0x0 0x0 0x0 0x0 0x0 0x0 0x0 0x0 0x0 0x0
DEBUG:pymodbus.logging:Processing: 0x0 0x0 0x0 0x0 0x0 0x0 0x0 0x0 0x0 0x0 0x0 0x0 0x0 0x0 0x0 0x0 0x0 0x0 0x0 0x0 0x0 0x0 0x0 0x0 0x0 0x0 0x0 0x0 0x0 0x0 0x0 0x0 0x0 0x0 0x0 0x0 0x0 0x0 0x0 0x0 0x0 0x0 0x0 0x0 0x0 0x0 0x0 0x0 0x0 0x0 0x0 0x0 0x0 0x0 0x0 0x0 0x0 0x0 0x0 0x0 0x0 0x0 0x0 0x0 0x0 0x0 0x0 0x0 0x0 0x0 0x0 0x0 0x0 0x0 0x0
DEBUG:pymodbus.logging:Getting transaction 255
DEBUG:pymodbus.logging:Changing transaction state from "PROCESSING REPLY" to "TRANSACTION_COMPLETE"
Failed to read data, reconnecting... 'ModbusIOException' object has no attribute 'registers'

magorm, 2023-12-11:
For the DB9, its 2(rx), 3(tx) and 5(gnd)?

cole8888, 2023-12-11:
Black (controller rx) goes to pin 2, White (controller tx) goes to pin 3, red (controller gnd) goes to pin 5.

Remember that the pin numbers reverse when comparing the male/female connectors:
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

magorm, 2023-12-11:
Here's my connection. Not sure if the problem is the RJ12?

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

magorm, 2023-12-11:
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

magorm, 2023-12-11:
slave=255
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

magorm, 2023-12-11:
Serial Enablement: I am using /dev/ttyS0

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

magorm, 2023-12-12:
I was able to make it work! Thanks so much @cole8888 ! You are right the problem is wrong connection.

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

Closed 2023-12-12.

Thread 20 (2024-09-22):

Use with RS485?

korishan, 2024-09-22:
Would this project work with RS485 connections?  Would just replacing the RS232 with the RS485 adapter work?
I have a PowMr 5k Hybrid Inverter and right now I'm using the SNRE software to do the monitoring. Tho it is very basic and doesn't upload any information to MQTT or other storage.

I've been trying to get a working bridge to dump the data to influx and bring it into Home Assistant, but it's been trying times.

cole8888, 2024-09-22:
I'm not really sure this project would be best for that application, this is only really intended for the SRNE charge controllers and an inverter likely uses very different addresses for all the values you'd need. Also, I tried using RS485 with the charge controller but I wasn't able to get it to work, but the inverter may be different.

It looks like there are other projects specifically for powermr inverters like this one: https://github.com/leodesigner/powmr_comm

korishan, 2024-09-22:
Yeah, I've already tried using Leodesigner's code. I couldn't get it working. I don't know what the issue is.  Thanks for replying tho 👍

Zatarraz, 2025-09-15:
In my opinion the addresses are the same: I connected an elfin ew11a to the rs485 and, as a pure layman, I managed to obtain this data:

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

So i think that address and modbus are compatibile.

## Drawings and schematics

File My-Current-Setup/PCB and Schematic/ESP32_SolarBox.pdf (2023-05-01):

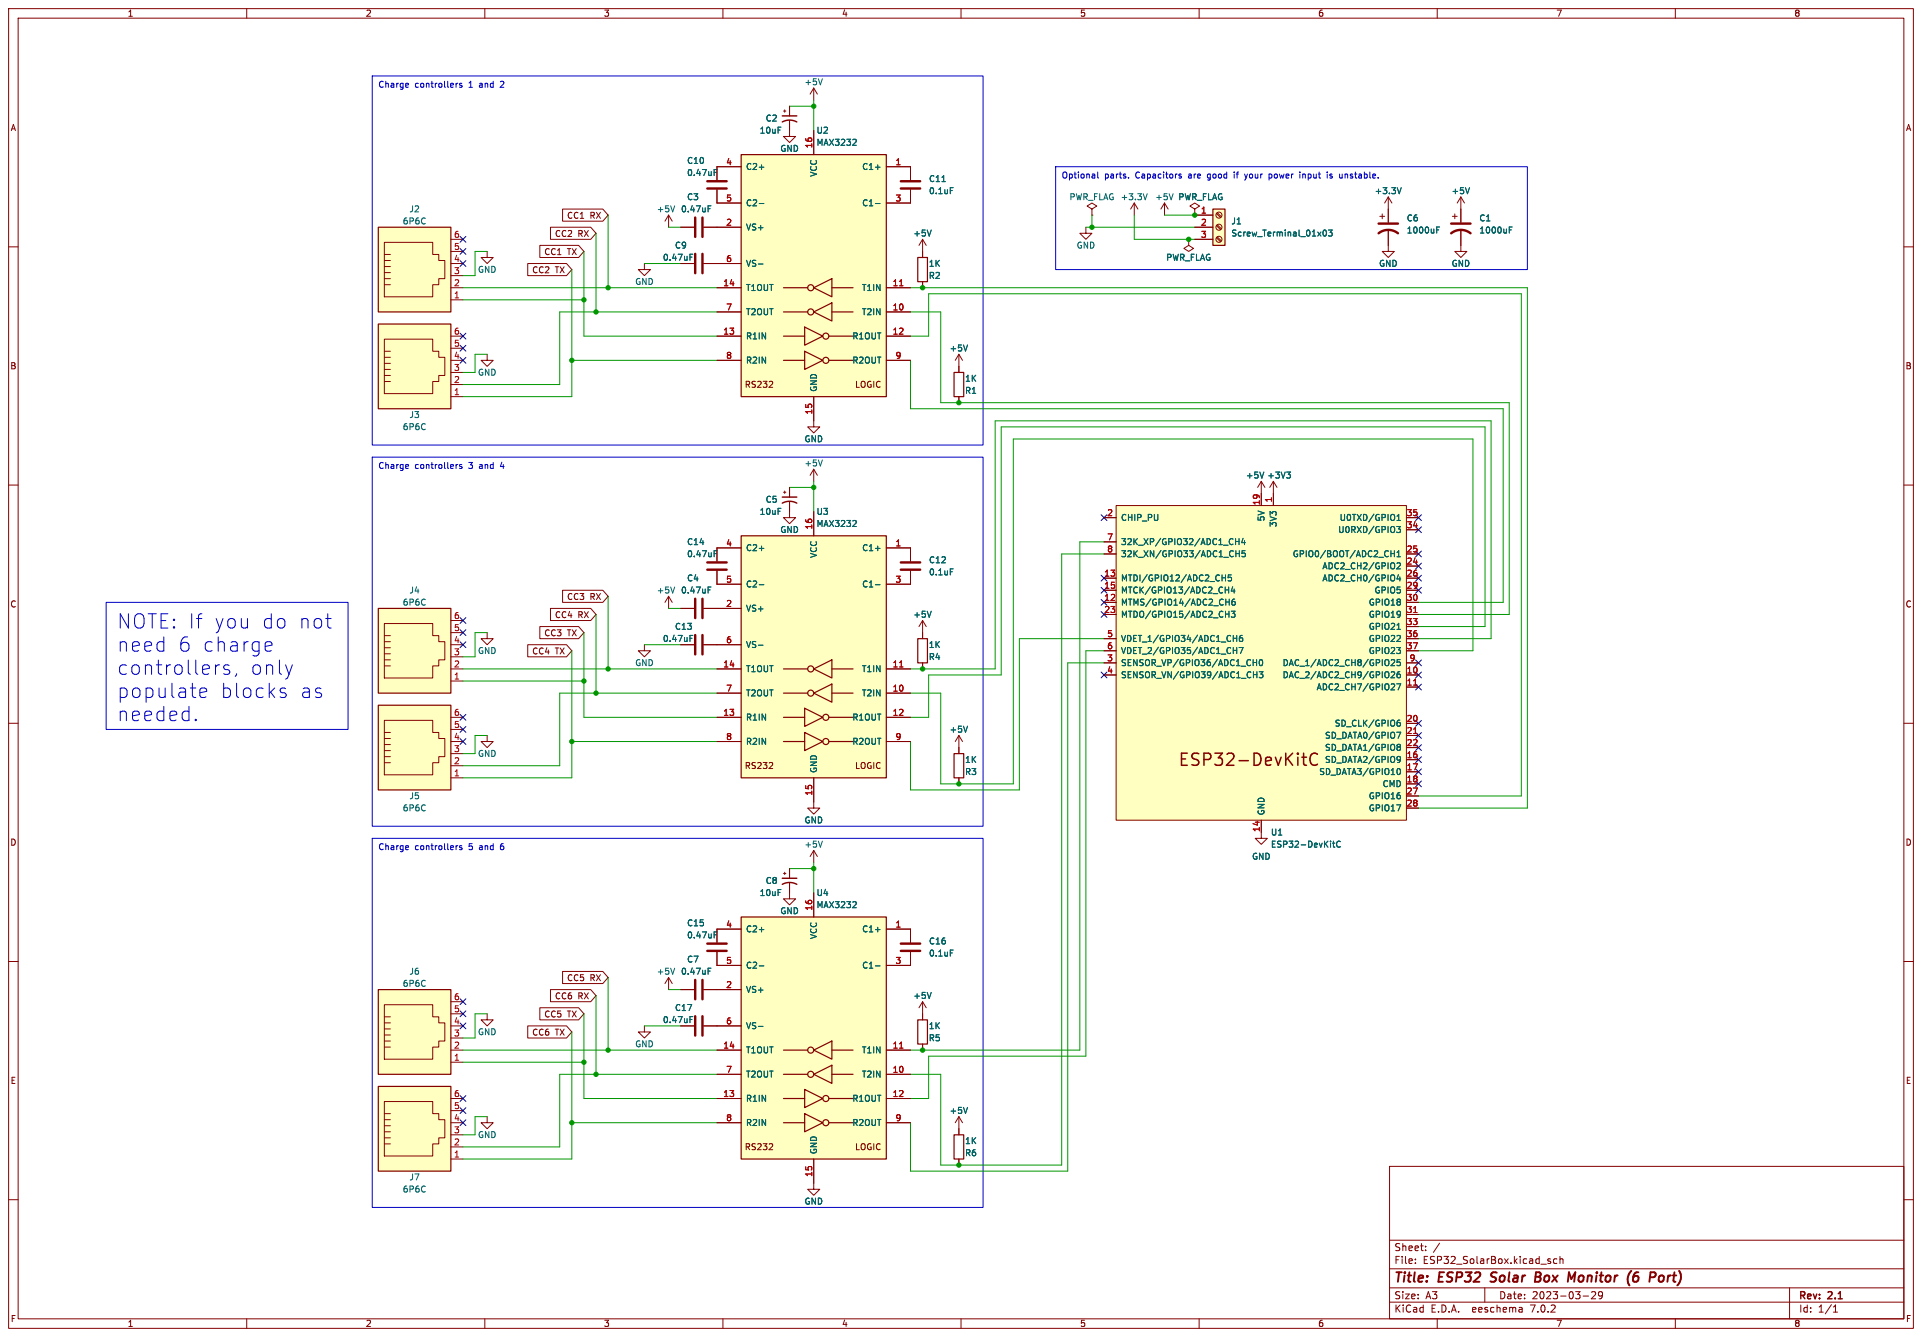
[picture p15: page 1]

CC2 TX CC1 TXCC1 RX CC3 RX CC4 RX CC2 RX CC3 TX

+3.3V CC4 TXCC5 RX CC5 TX CC6 RX CC6 TX
+5V GND GND

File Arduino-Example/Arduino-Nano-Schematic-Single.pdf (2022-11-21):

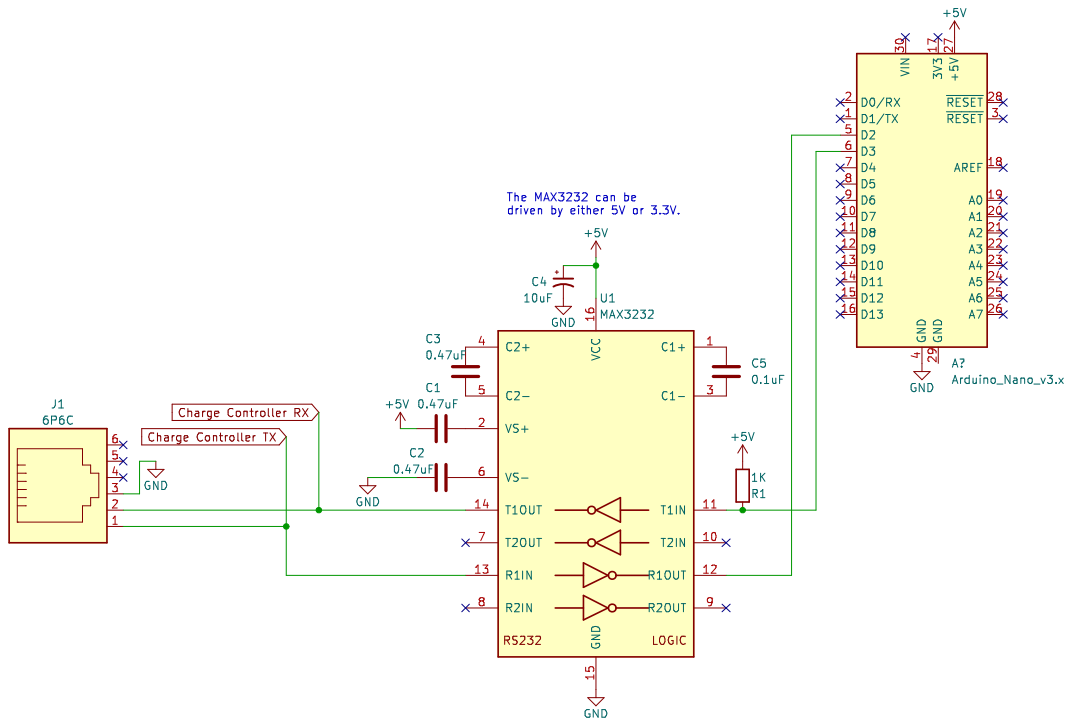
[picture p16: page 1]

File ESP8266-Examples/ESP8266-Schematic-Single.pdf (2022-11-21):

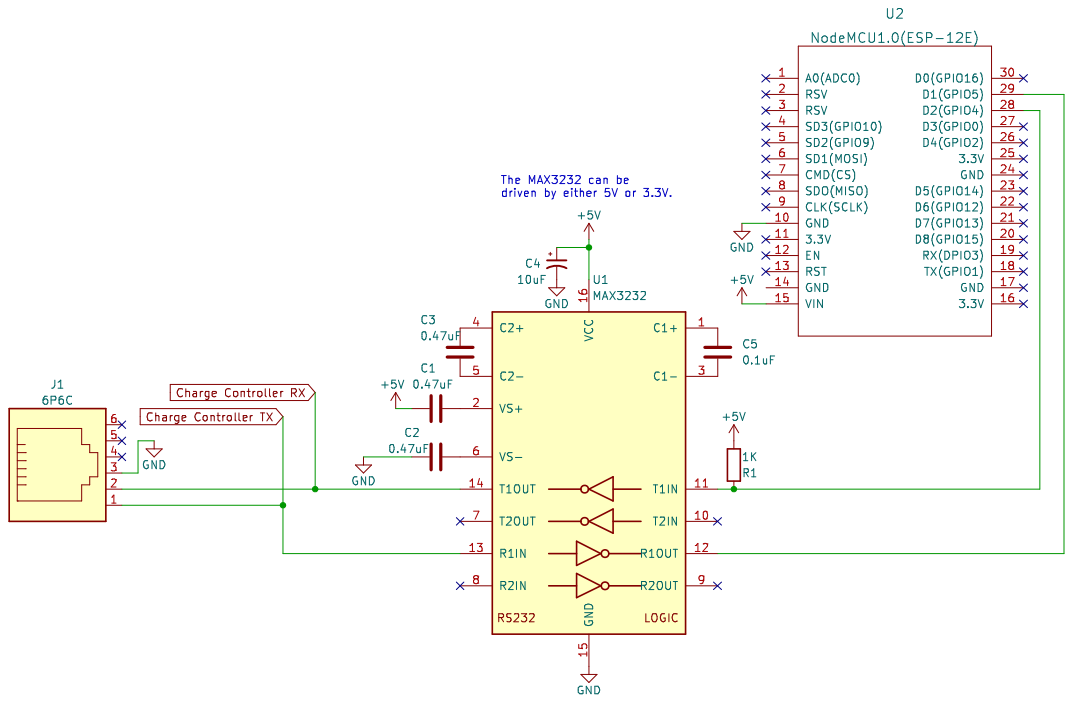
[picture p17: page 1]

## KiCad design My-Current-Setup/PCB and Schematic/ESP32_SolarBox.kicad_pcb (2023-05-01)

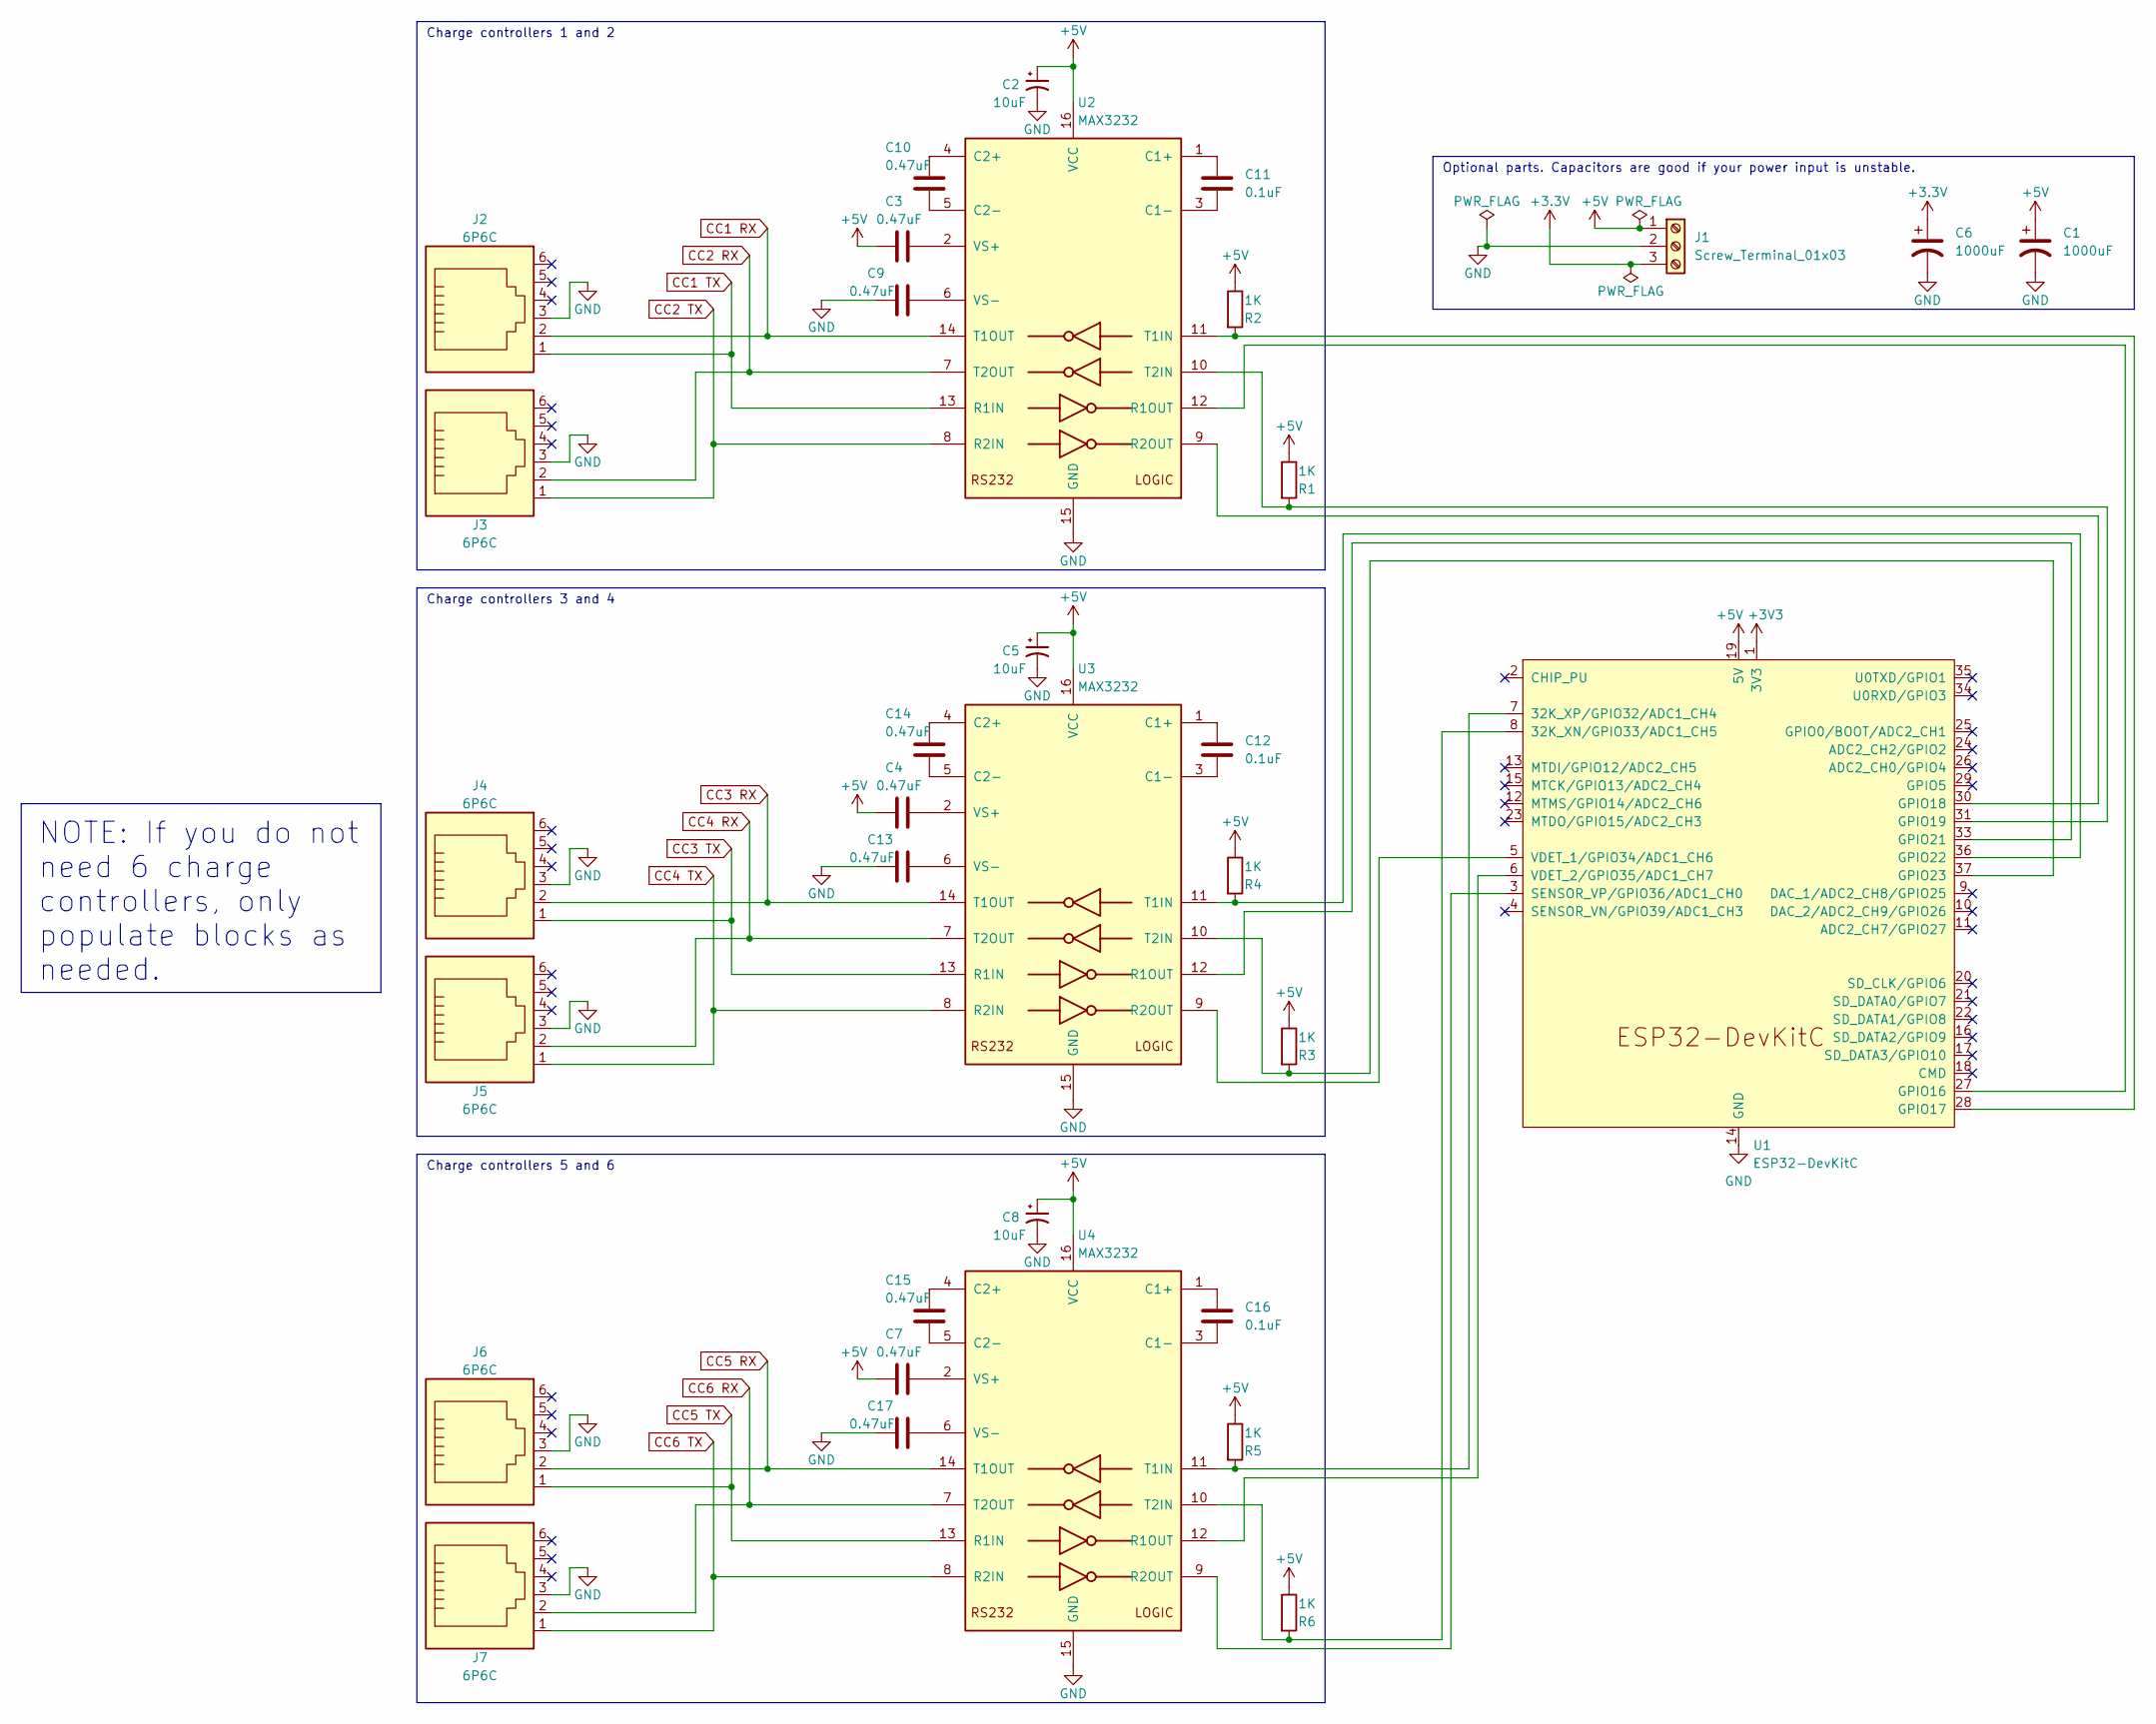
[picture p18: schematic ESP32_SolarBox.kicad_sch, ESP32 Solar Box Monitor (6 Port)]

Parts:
C1, C6: 1000uF; CP_Radial_D12.5mm_P5.00mm
C2, C5, C8: 10uF; CP_Radial_D6.3mm_P2.50mm
C3, C4, C7, C9, C10, C13, C14, C15, C17: 0.47uF; C_Disc_D4.7mm_W2.5mm_P5.00mm
C11, C12, C16: 0.1uF; C_Disc_D5.0mm_W2.5mm_P2.50mm
J1: Screw_Terminal_01x03; TerminalBlock_Phoenix_PT-1,5-3-3.5-H_1x03_P3.50mm_Horizontal
J2, J3, J4, J5, J6, J7: 6P6C; RJ12_Amphenol_54601
R1, R2, R3, R4, R5, R6: 1K; R_Axial_DIN0207_L6.3mm_D2.5mm_P10.16mm_Horizontal
U1: ESP32-DevKitC
U2, U3, U4: MAX3232; DIP-16_W7.62mm

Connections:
+5V: C1.1, C2.1, C3.2, C4.2, C5.1, C7.2, C8.1, J1.1, R1.1, R2.1, R3.1, R4.1, R5.1, R6.1, U1.19 (5V), U2.16 (VCC), U3.16 (VCC), U4.16 (VCC)
CC1 RX: J2.2, U2.14 (T1OUT)
CC1 TX: J2.1, U2.13 (R1IN)
CC2 RX: J3.2, U2.7 (T2OUT)
CC2 TX: J3.1, U2.8 (R2IN)
CC3 RX: J4.2, U3.14 (T1OUT)
CC3 TX: J4.1, U3.13 (R1IN)
CC4 RX: J5.2, U3.7 (T2OUT)
CC4 TX: J5.1, U3.8 (R2IN)
CC5 RX: J6.2, U4.14 (T1OUT)
CC5 TX: J6.1, U4.13 (R1IN)
CC6 RX: J7.2, U4.7 (T2OUT)
CC6 TX: J7.1, U4.8 (R2IN)
GND: C1.2, C2.2, C5.2, C6.2, C8.2, C9.2, C13.2, C17.2, J1.2, J2.3, J3.3, J4.3, J5.3, J6.3, J7.3, U1.14 (GND), U1.32 (GND), U1.38 (GND), U2.15 (GND), U3.15 (GND), U4.15 (GND)
unnamed: R6.2, U1.8 (32K_XN/GPIO33/ADC1_CH5), U4.10 (T2IN)
unnamed: R5.2, U1.7 (32K_XP/GPIO32/ADC1_CH4), U4.11 (T1IN)
unnamed: U1.27 (GPIO16), U2.12 (R1OUT)
unnamed: R2.2, U1.28 (GPIO17), U2.11 (T1IN)
unnamed: U1.30 (GPIO18), U2.9 (R2OUT)
unnamed: R1.2, U1.31 (GPIO19), U2.10 (T2IN)
unnamed: U1.33 (GPIO21), U3.12 (R1OUT)
unnamed: R4.2, U1.36 (GPIO22), U3.11 (T1IN)
unnamed: R3.2, U1.37 (GPIO23), U3.10 (T2IN)
unnamed: U1.3 (SENSOR_VP/GPIO36/ADC1_CH0), U4.9 (R2OUT)
unnamed: U1.5 (VDET_1/GPIO34/ADC1_CH6), U3.9 (R2OUT)
unnamed: U1.6 (VDET_2/GPIO35/ADC1_CH7), U4.12 (R1OUT)
unnamed: C11.1, U2.1 (C1+)
unnamed: C11.2, U2.3 (C1-)
unnamed: C10.1, U2.4 (C2+)
unnamed: C10.2, U2.5 (C2-)
unnamed: C3.1, U2.2 (VS+)
unnamed: C9.1, U2.6 (VS-)
unnamed: C12.1, U3.1 (C1+)
unnamed: C12.2, U3.3 (C1-)
unnamed: C14.1, U3.4 (C2+)
unnamed: C14.2, U3.5 (C2-)
unnamed: C4.1, U3.2 (VS+)
unnamed: C13.1, U3.6 (VS-)
unnamed: C16.1, U4.1 (C1+)
unnamed: C16.2, U4.3 (C1-)
unnamed: C15.1, U4.4 (C2+)
unnamed: C15.2, U4.5 (C2-)
unnamed: C7.1, U4.2 (VS+)
unnamed: C17.1, U4.6 (VS-)

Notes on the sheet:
NOTE: If you do not need 6 charge controllers, only populate blocks as needed.
Charge controllers 3 and 4
Charge controllers 5 and 6
Optional parts. Capacitors are good if your power input is unstable.
Charge controllers 1 and 2

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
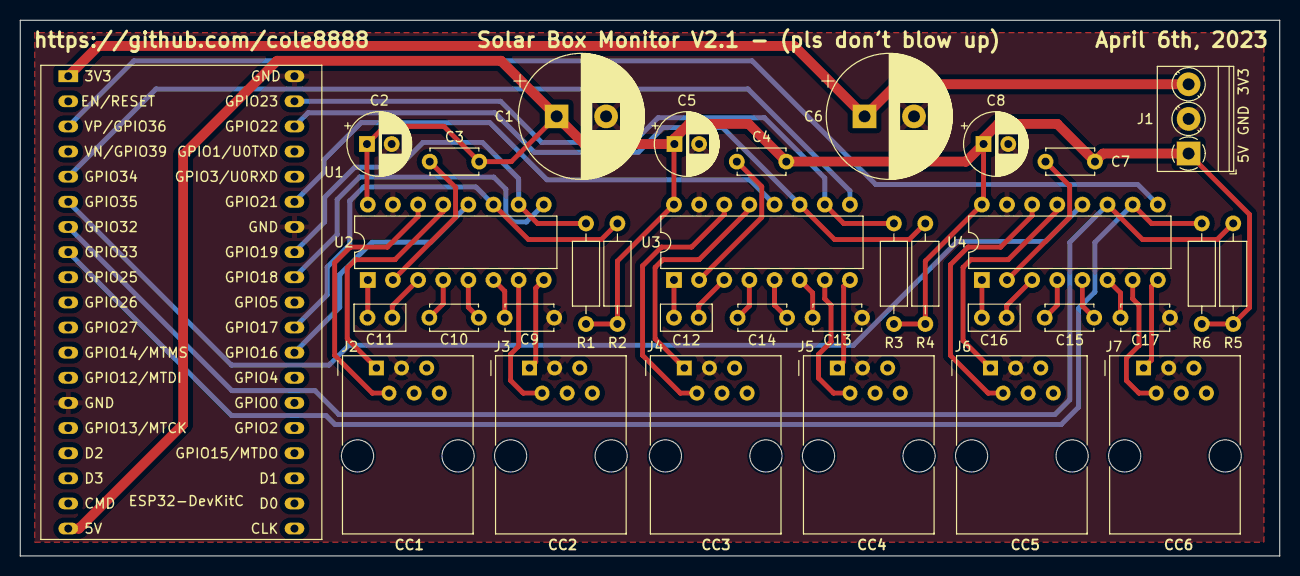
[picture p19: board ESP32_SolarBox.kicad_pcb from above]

Board: 2 copper layers, 127.3 x 54.1 mm, 34 parts (0 on the bottom side), 45 nets.

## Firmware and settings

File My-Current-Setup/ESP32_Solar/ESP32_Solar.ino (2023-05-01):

/*
    Cole L - 1st May 2023 - https://github.com/cole8888/SRNE-Solar-Charge-Controller-Monitor

    Retrieve data from SRNE solar charge controllers using an ESP32 and publish that data as JSON to an MQTT Server.

    This also has OTA updates and WebSerial.

    See images and schematic for wiring details.
*/

/*
    Required libraries.
*/
#include <ArduinoJson.h>    // https://github.com/bblanchon/ArduinoJson
#include <ModbusMaster.h>   // https://github.com/4-20ma/ModbusMaster
#include <PubSubClient.h>   // https://github.com/knolleary/pubsubclient
#include <SoftwareSerial.h> // https://github.com/plerup/espsoftwareserial/
#include <WiFi.h>

/*
    Optional libraries that support features that can be removed if wanted.
*/
#include <AsyncElegantOTA.h>   // https://github.com/ayushsharma82/AsyncElegantOTA
#include <AsyncTCP.h>          // https://github.com/me-no-dev/AsyncTCP/
#include <ESPAsyncWebServer.h> // https://github.com/me-no-dev/ESPAsyncWebServer/
#include <WebSerial.h>         // https://github.com/ayushsharma82/WebSerial

/*
    WiFi Settings.
*/
#define WIFI_SSID "CHANGE_ME!!!"
#define WIFI_PASS "CHANGE_ME!!!"

/*
    MQTT related settings. You many need to change these depending on your implementation.
*/
#define MQTT_PORT 1883                  // Port to use for MQTT.
#define MQTT_SERVER_ADDR "192.168.2.50" // Address of the MQTT broker.
#define MQTT_USER "CHANGE_ME!!!"        // Username for MQTT server.
#define MQTT_PASS "CHANGE_ME!!!"        // Password for MQTT server.
#define MQTT_CLIENT_ID "ESP32"          // Client identifier for MQTT.
#define CC_TOPIC_PREFIX "CC"            // Prefix of the charge controller topic. A number will be appended to this (ex: CC1).
#define MQTT_RECONNECT_DELAY 5000       // Delay in ms before to wait before reconnecting to the MQTT server.

/*
    Over The Air update settings.
*/
#define OTA_FLASH_USER "CHANGE_ME!!!" // Username for OTA update page.
#define OTA_FLASH_PASS "CHANGE_ME!!!" // Password for OTA update page.

/*
    Modbus Constants

    All charge controllers will respond to address 255 no matter what their actual address is, this is useful if you do not know what address to use.
    You can try using 1 here instead of 255, but it is not guaranteed to work.
*/
#define NUM_REGISTERS 35
#define MODBUS_SLAVE_ADDR 255
#define MODBUS_REQUEST_START_ADDR 256

/*
    Other settings.
*/
#define NUM_CHARGE_CONTROLLERS 3                             // Number of charge controllers connected. Max of 6 without adjusting program.
#define NUM_HW_SERIAL 1                                      // Number of charge controllers using HW Serial. Max of 2. 3 should be possible, but you will need to adjust the program.
#define NUM_SW_SERIAL NUM_CHARGE_CONTROLLERS - NUM_HW_SERIAL // Number of charge controllers using software serial. Some controllers may not like SW serial, use HW instead.
#define REQUEST_DELAY 3000                                   // Delay in ms between rounds of polling all the charge controllers.
#define WIFI_SINGLE_WAIT_DELAY 500                           // Delay in ms for a single wait for the wifi to connect (time for a "." to show up on console).
#define SETUP_FINISH_DELAY 100                               // Delay in ms to wait after setup has finished to allow everything to settle down.
#define JSON_BUFFER_SIZE 2048                                // Maximum size for the JSON string.

/*
    Describes the different states the program can be in. Repeats for each controller.
*/
enum STATE {
    WAIT = 0,
    QUERY = 1,
    TRANSMIT = 2
};
STATE state;

/*
    Array of charging mode strings.
    These are the states the charge controller can be in when charging the battery.
*/
const char *chargeModes[7] = {
    "OFF",      // 0
    "NORMAL",   // 1
    "MPPT",     // 2
    "EQUALIZE", // 3
    "BOOST",    // 4
    "FLOAT",    // 5
    "CUR_LIM"   // 6 (Current limiting)
};

/*
    Array of fault codes.
    These are all the possible faults the charge controller can indicate.
    Multiple faults can be thrown at the same time.
*/
const char *faultCodes[15] = {
    "Charge MOS short circuit",      // (16384 | 01000000 00000000)
    "Anti-reverse MOS short",        // (8192  | 00100000 00000000)
    "PV panel reversely connected",  // (4096  | 00010000 00000000)
    "PV working point over voltage", // (2048  | 00001000 00000000)
    "PV counter current",            // (1024  | 00000100 00000000)
    "PV input side over-voltage",    // (512   | 00000010 00000000)
    "PV input side short circuit",   // (256   | 00000001 00000000)
    "PV input overpower",            // (128   | 00000000 10000000)
    "Ambient temp too high",         // (64    | 00000000 01000000)
    "Controller temp too high",      // (32    | 00000000 00100000)
    "Load over-power/current",       // (16    | 00000000 00010000)
    "Load short circuit",            // (8     | 00000000 00001000)
    "Battery undervoltage warning",  // (4     | 00000000 00000100)
    "Battery overvoltage",           // (2     | 00000000 00000010)
    "Battery over-discharge"         // (1     | 00000000 00000001)
};

// Create the WiFi and MQTT clients.
WiFiClient wifiClient;
PubSubClient client(MQTT_SERVER_ADDR, MQTT_PORT, wifiClient);

// Create the modbus nodes for each charge controller.
ModbusMaster nodes[NUM_CHARGE_CONTROLLERS];

// Software serial ports for talking to the charge controllers.
SoftwareSerial serialPorts[NUM_SW_SERIAL];

// Webserver for OTA updates and WebSerial.
AsyncWebServer server(80);

/*
    RX and TX pins for serial ports.
    If using my PCB design, do not change these.
    If you plan to change these, make sure you verify your pin is usable, eg: any ADC2 pins cannot be used since WiFi needs them.
    Heads up, some of these are input only.
*/
const uint8_t serialPins[2][6] = {{16, 18, 21, 34, 35, 36}, {17, 19, 22, 23, 32, 33}};

/*
    Indexes of the charge controller(s) to use HardwareSerial for instead of SoftwareSerial.
    Some charge controllers do not play nicely with SoftwareSerial,
    such as my ML2440 (CC3) which fails to respond when SoftwareSerial is used, but my ML4860's are fine.

    Indexes start at 0, so index for CC3 is index 2.

    If only using SoftwareSerial, set this to: {}
*/
const uint8_t hwSerialIndexes[NUM_HW_SERIAL] = {2};

// Charge controller index we are talking to / publishing data from at the moment.
uint8_t currentCC;

// Store all the raw data collected from the current charge controller.
uint16_t chargeControllerRegisterData[NUM_REGISTERS];

// Was there an error when reading from the current charge controller?
uint8_t modbusErr;

// Last time isTime() was run and returned 1.
unsigned long lastTime;

// Store the formatted json string for publishing over MQTT.
char registerDataJson[JSON_BUFFER_SIZE];

void setup() {
    Serial.begin(115200);
    Serial.println(F("Started serial!"));

    // Setup the WiFi and wait for connection.
    WiFi.begin(WIFI_SSID, WIFI_PASS);
    while (WiFi.status() != WL_CONNECTED) {
        Serial.print(F("."));
        delay(WIFI_SINGLE_WAIT_DELAY);
    }
    Serial.print(F("\nWiFi Connected\nIP: "));
    Serial.println(WiFi.localIP());

    // Setup OTA updates. (In browser go to: <IP Address>/update).
    AsyncElegantOTA.begin(&server, OTA_FLASH_USER, OTA_FLASH_PASS);

    // WebSerial for remote monitoring (In browser go to: <IP Address>/webserial).
    WebSerial.begin(&server);

    // Start the webserver.
    server.begin();
    Serial.println(F("HTTP server started"));

    // Connect to MQTT Broker.
    if (!client.setBufferSize(JSON_BUFFER_SIZE)) {
        Serial.println(F("MQTT buffer allocation failed! (Halting start-up)"));
        while (1)
            ;
    }
    while (!client.connect(MQTT_CLIENT_ID, MQTT_USER, MQTT_PASS)) {
        Serial.println(F("MQTT Connection failed..."));
        delay(MQTT_RECONNECT_DELAY);
    }
    Serial.println(F("MQTT Connected"));

    // Setup the serial ports and assign them to the modbus nodes.
    uint8_t hwSerialCount = 0;
    for (uint8_t i = 0; i < NUM_CHARGE_CONTROLLERS; i++) {
        uint8_t isHW_Serial = 0;
        // See if charge controller should use HardwareSerial instead of SoftwareSerial.
        if (NUM_HW_SERIAL) {
            for (uint8_t j = 0; j < NUM_HW_SERIAL; j++) {
                if (i == hwSerialIndexes[j]) {
                    if (j == 0) {
                        Serial1.begin(9600, SERIAL_8N1, serialPins[0][i], serialPins[1][i]);
                        nodes[i].begin(MODBUS_SLAVE_ADDR, Serial1);
                    } else if (j == 1) {
                        Serial2.begin(9600, SERIAL_8N1, serialPins[0][i], serialPins[1][i]);
                        nodes[i].begin(MODBUS_SLAVE_ADDR, Serial2);
                    }
                    isHW_Serial = 1;
                    hwSerialCount++;
                    break;
                }
            }
        }
        if (!isHW_Serial) {
            serialPorts[i - hwSerialCount].begin(9600, SWSERIAL_8N1, serialPins[0][i], serialPins[1][i]);
            nodes[i].begin(MODBUS_SLAVE_ADDR, serialPorts[i - hwSerialCount]);
        }
    }

    currentCC = NUM_CHARGE_CONTROLLERS;
    state = WAIT;

    delay(SETUP_FINISH_DELAY);

    lastTime = millis();
}

/*
    Helper function to handle the sign bit for negative temperatures.
*/
int getRealTemp(int temp) {
    return temp / 128 ? -(temp % 128) : temp;
}

/*
    millis() Rollover safe time delay tracking.
*/
uint8_t isTime() {
    if (millis() - lastTime >= REQUEST_DELAY) {
        lastTime = millis();
        return 1;
    }
    return 0;
}

/*
    Publish the JSON data to MQTT.
*/
void pub() {
    // Build the topic name.
    int topicSize = strlen(CC_TOPIC_PREFIX) + 2; // +1 for null terminator and +1 for the charge controller number after the CC prefix.
    char *tempTopic = (char *)malloc(topicSize);
    snprintf(tempTopic, topicSize, "%s%d", CC_TOPIC_PREFIX, currentCC + 1);

    if (!client.publish(tempTopic, registerDataJson)) {
        // If error then try reconnecting and publishing again.
        // Serial.println(F("MQTT Failed to send"));
        WebSerial.println(F("MQTT Failed to send"));
        if (client.connect(MQTT_CLIENT_ID, MQTT_USER, MQTT_PASS)) {
            client.publish(tempTopic, registerDataJson);
        }
    }
    free(tempTopic);
}

/*
    Convert the charge controller register data into a formatted JSON string.
    Register addresses were figured out from the modbus document.
*/
void registerToJson() {
    StaticJsonDocument<JSON_BUFFER_SIZE> doc;
    if (modbusErr) {
        doc["modbusError"] = true;
    } else {
        // We need to account for the load being on when determining the charging mode.
        int loadOffset = chargeControllerRegisterData[32] > 6 ? 32768 : 0;

        doc["modbusError"] = false;

        JsonObject controller = doc.createNestedObject("controller");
        controller["chargingMode"] = chargeModes[chargeControllerRegisterData[32] - loadOffset];
        controller["temperature"] = getRealTemp(chargeControllerRegisterData[3] >> 8);
        controller["days"] = chargeControllerRegisterData[21];
        controller["overDischarges"] = chargeControllerRegisterData[22];
        controller["fullCharges"] = chargeControllerRegisterData[23];

        JsonObject charging = doc.createNestedObject("charging");
        charging["amps"] = chargeControllerRegisterData[2] * 0.01;
        charging["maxAmps"] = chargeControllerRegisterData[13] * 0.01;
        charging["watts"] = chargeControllerRegisterData[9];
        charging["maxWatts"] = chargeControllerRegisterData[15];
        charging["dailyAmpHours"] = chargeControllerRegisterData[17];
        charging["totalAmpHours"] = ((chargeControllerRegisterData[24] * 65536 + chargeControllerRegisterData[25]) * 0.001);
        charging["dailyPower"] = chargeControllerRegisterData[19] * 0.001;
        charging["totalPower"] = ((chargeControllerRegisterData[28] * 65536 + chargeControllerRegisterData[29]) * 0.001);

        JsonObject battery = doc.createNestedObject("battery");
        battery["stateOfCharge"] = chargeControllerRegisterData[0];
        battery["volts"] = chargeControllerRegisterData[1] * 0.1;
        battery["minVolts"] = chargeControllerRegisterData[11] * 0.1;
        battery["maxVolts"] = chargeControllerRegisterData[12] * 0.1;
        battery["temperature"] = getRealTemp(chargeControllerRegisterData[3] & 0xFF);

        JsonObject panels = doc.createNestedObject("panels");
        panels["volts"] = chargeControllerRegisterData[7] * 0.1;
        panels["amps"] = chargeControllerRegisterData[8] * 0.01;

        JsonObject load = doc.createNestedObject("load");
        load["state"] = chargeControllerRegisterData[10] ? true : false;
        load["volts"] = chargeControllerRegisterData[4] * 0.1;
        load["amps"] = chargeControllerRegisterData[5] * 0.01;
        load["watts"] = chargeControllerRegisterData[6];
        load["maxAmps"] = chargeControllerRegisterData[14] * 0.01;
        load["maxWatts"] = chargeControllerRegisterData[16];
        load["dailyAmpHours"] = chargeControllerRegisterData[18];
        load["totalAmpHours"] = ((chargeControllerRegisterData[26] * 65536 + chargeControllerRegisterData[27]) * 0.001);
        load["dailyPower"] = chargeControllerRegisterData[20] * 0.001;
        load["totalPower"] = ((chargeControllerRegisterData[30] * 65536 + chargeControllerRegisterData[31]) * 0.001);

        JsonArray faults = doc.createNestedArray("faults");
        int faultId = chargeControllerRegisterData[34];
        uint8_t count = 0;
        while (faultId != 0) {
            if (faultId >= pow(2, 15 - count)) {
                faults.add(faultCodes[count - 1]);
                faultId -= pow(2, 15 - count);
            }
            count += 1;
        }
    }
    serializeJson(doc, registerDataJson);
}

/*
    Request data from the charge controller and store it.
*/
void readNode() {
    static uint32_t i;
    i++;
    // set word 0 of TX buffer to least-significant word of counter (bits 15..0)
    nodes[currentCC].setTransmitBuffer(0, lowWord(i));
    // set word 1 of TX buffer to most-significant word of counter (bits 31..16)
    nodes[currentCC].setTransmitBuffer(1, highWord(i));

    uint8_t result = nodes[currentCC].readHoldingRegisters(MODBUS_REQUEST_START_ADDR, NUM_REGISTERS);
    if (result == nodes[currentCC].ku8MBSuccess) {
        modbusErr = 0;
        // Serial.print(F("Successfully read from CC"));
        // Serial.println(currentCC);
        WebSerial.print(F("Successfully read from CC"));
        WebSerial.println(currentCC + 1);

        for (int j = 0; j < NUM_REGISTERS; j++) {
            chargeControllerRegisterData[j] = nodes[currentCC].getResponseBuffer(j);
        }
    } else {
        modbusErr = 1;
        // Serial.print(F("Failed to read from CC"));
        // Serial.print(currentCC+1);
        // Serial.print(F(" ("));
        // Serial.print(result, HEX);
        // Serial.println(F(")"));
        WebSerial.print(F("Failed to read from CC"));
        WebSerial.print(currentCC + 1);
        WebSerial.print(F(" ("));
        WebSerial.print(String(result, HEX));
        WebSerial.println(F(")"));
    }
}

/*
    Reconnect to the MQTT broker.
*/
void reconnectMQTT() {
    while (!client.connected()) {
        if (client.connect(MQTT_CLIENT_ID, MQTT_USER, MQTT_PASS)) {
            // Serial.println(F("MQTT Reconnected"));
            WebSerial.println(F("MQTT Reconnected"));
        } else {
            // Serial.print(F("MQTT Failed to reconnect: "));
            // Serial.println(client.state());
            WebSerial.print(F("MQTT Failed to reconnect: "));
            WebSerial.println(client.state());
            delay(MQTT_RECONNECT_DELAY);
        }
    }
}

void loop() {
    if (!client.loop()) {
        reconnectMQTT();
    } else if (state == WAIT) {
        // Only wait after cycling through all the controllers.
        if (currentCC >= NUM_CHARGE_CONTROLLERS) {
            if (isTime()) {
                currentCC = 0;
                state = QUERY;
            }
        } else {
            state = QUERY;
        }
    } else if (state == QUERY) {
        readNode();
        state = TRANSMIT;
    } else if (state == TRANSMIT) {
        registerToJson();
        pub();
        currentCC++;
        state = WAIT;
    } else {
        state = WAIT;
    }
}

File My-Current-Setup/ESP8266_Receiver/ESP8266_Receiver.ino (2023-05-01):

/*
    Cole L - 1st May 2023 - https://github.com/cole8888/SRNE-Solar-Charge-Controller-Monitor

    This ESP8266 subscribes to MQTT topics for charge controller data and Tasmota smart plug statistics.

    This code runs on an ESP8266 NODEMCU 0.9 module.
*/

#include <ArduinoJson.h>       // https://github.com/bblanchon/ArduinoJson
#include <ESP8266WiFi.h>       // Enables The WiFi radio on the ESP8266.
#include <LiquidCrystal_I2C.h> // LCD
#include <PubSubClient.h>      // https://github.com/knolleary/pubsubclient

/*
    WiFi Settings.
*/
#define WIFI_SSID "CHANGE_ME!!!"
#define WIFI_PASS "CHANGE_ME!!!"

/*
    MQTT related settings. You many need to change these depending on your implementation.
*/
#define MQTT_PORT 1883                  // Port to use for MQTT.
#define MQTT_SERVER_ADDR "192.168.2.50" // Address of the MQTT server.
#define MQTT_USER "CHANGE_ME!!!"        // Username for the MQTT server.
#define MQTT_PASS "CHANGE_ME!!!"        // Password for the MQTT server.
#define MQTT_CLIENT_ID "ESP8266"        // Client identifier for MQTT.
#define MQTT_RECONNECT_DELAY 5000
#define NUM_MQTT_TOPICS 6

/*
    Other constant and settings.
*/
#define NUM_CHARGE_CONTROLLERS 3     // Number of nodes that will report charge controller data.
#define NUM_PLUGS 3                  // Number of plugs to use for calculating total power consumption.
#define WIFI_SINGLE_WAIT_DELAY 500   // Delay in ms for a single wait for the wifi to connect (time for a "." to show uo on lcd)
#define LCD_REFRESH_NODE 2           // Receiving a transmission from this node will cause the LCD to update.
#define BATTERY_VOLTAGE_NODE 0       // Receiving a transmission from this node will cause the LCD to update.
#define ROW_MAX_CHARS 21             // Maximum number of characters for row 1, includes null.
#define WATTS_STRING_MAX_CHARS 6     // Maximum number of characters for the watts string for the lcd. Includes the W unit and null.
#define NUM_CHARS_FOR_CC_COMPARE 3   // Number of characters in the topic name to compare when determining which charge controller a message came from.
#define NUM_CHARS_FOR_PLUG_COMPARE 7 // Number of characters in the topic name to compare when determining which plug a message came from.
#define CC_JSON_BUFFER_SIZE 2048     // Maximum size for the JSON string.
#define PLUG_JSON_BUFFER_SIZE 2048   // Maximum size for the JSON string received from the plug.

/*
    Describes the different states the program can be in.
*/
enum SOURCE {
    CC = 0,
    PLUG = 1,
};
SOURCE msgSource;

const char *mqttTopics[NUM_MQTT_TOPICS] = {
    "CC1",                     // 0
    "CC2",                     // 1
    "CC3",                     // 2
    "tele/WaterHeater/SENSOR", // 3
    "tele/15AMP/SENSOR",       // 4
    "tele/20AMP/SENSOR"        // 5
};

int ccPower[NUM_CHARGE_CONTROLLERS] = {0, 0, 0};

uint8_t ccError[NUM_CHARGE_CONTROLLERS] = {0, 0, 0};

int plugPower[NUM_PLUGS] = {0, 0, 0};

float battVolts = 0.0;

int sums[2] = {0, 0};

StaticJsonDocument<CC_JSON_BUFFER_SIZE> cc_doc[NUM_CHARGE_CONTROLLERS];
StaticJsonDocument<PLUG_JSON_BUFFER_SIZE> plug_doc[NUM_PLUGS];

// Create the LCD device.
LiquidCrystal_I2C lcd(0x27, 20, 4);

void sumPower() {
    sums[0] = 0;
    sums[1] = 0;
    for (int i = 0; i < NUM_CHARGE_CONTROLLERS; i++) {
        sums[0] += ccPower[i];
    }
    for (int i = 0; i < NUM_PLUGS; i++) {
        sums[1] += plugPower[i];
    }
}

// Called whenever an MQTT message is received.
void callback(char *topic, byte *payload, unsigned int length) {
    int index = -1; // Which controller / plug sent the message.

    // Where did the message come from?
    for (int i = 0; i < NUM_MQTT_TOPICS; i++) {
        if (i < NUM_CHARGE_CONTROLLERS) {
            if (strncmp(topic, mqttTopics[i], NUM_CHARS_FOR_CC_COMPARE) == 0) {
                index = i;
                msgSource = CC;
                break;
            }
        } else {
            if (strncmp(topic, mqttTopics[i], NUM_CHARS_FOR_PLUG_COMPARE) == 0) {
                index = i - NUM_CHARGE_CONTROLLERS;
                msgSource = PLUG;
                break;
            }
        }
    }

    if (index < 0) {
        Serial.println(F("Unknown MQTT topic."));
    } else if (msgSource == CC) {
        if (length >= CC_JSON_BUFFER_SIZE) {
            Serial.print(F("Received message too large. ("));
            Serial.print(length);
            Serial.println(F(")"));
        } else {
            DeserializationError error = deserializeJson(cc_doc[index], (char *)payload);

            if (error) {
                Serial.print(F("deserializeJson() failed: "));
                Serial.println(error.f_str());
                return;
            } else {
                if (cc_doc[index]["modbusError"]) {
                    ccError[index] = 1;
                } else {
                    ccPower[index] = (int)cc_doc[index]["charging"]["watts"];
                    ccError[index] = 0;
                }
            }
        }
        if (index == BATTERY_VOLTAGE_NODE) {
            battVolts = (float)cc_doc[index]["battery"]["volts"];
        }
        if (index == LCD_REFRESH_NODE) {
            printLCD();
        }
    } else {
        if (length >= PLUG_JSON_BUFFER_SIZE) {
            Serial.print(F("Received message too large. ("));
            Serial.print(length);
            Serial.println(F(")"));
        } else {
            DeserializationError error = deserializeJson(plug_doc[index], (char *)payload);

            if (error) {
                Serial.print(F("deserializeJson() failed: "));
                Serial.println(error.f_str());
                return;
            } else {
                plugPower[index] = (int)plug_doc[index]["ENERGY"]["Power"];
            }
        }
    }
}

// Create the WiFi and MQTT clients.
WiFiClient wifiClient;
PubSubClient client(MQTT_SERVER_ADDR, MQTT_PORT, callback, wifiClient);

// Subscribe to all the requested MQTT topics.
void subscribeToTopics() {
    for (int i = 0; i < NUM_MQTT_TOPICS; i++) {
        client.subscribe(mqttTopics[i]);
    }
}
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

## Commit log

2021-06-22 Fix fault detection
    Was reading wrong register for controller faults. Need to read 0x0122 (290) and not 0x0121 (289). Had no way of testing this until recently I got a panel overvoltage fault by accident. Also the wrong fault text was being returned by one and needed an offset of -1 when selecting it. Not sure why and what the ramifications are for the first and last faults in the list.
    [SolarMonitor.py]
2021-07-03 Fix incorrect comment.
    Accidentally placed the wrong comments on the publish statements for the battery and controller temperatures.
2021-07-25 Create SolarMonitor.py
    Updated version with stuff cleaned up a bit. I no longer send strings for fault detection, I just send the raw charge controller data and let the client parse it.
    [SolarMonitor.py]
2022-05-11 Fix issue with high VOC values for arduino version and added fault data to raspberry pi version.
    [SOLAR_RECEIVE.ino, SOLAR_SEND_CC1.ino, SOLAR_SEND_CC2.ino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]
2022-10-08 Remove unused commented code, fix typo.
    [SOLAR_RECEIVE.ino, SOLAR_SEND_CC1.ino]
2022-11-20 Add CC3, add PCB and schematic.
    [SolarBox.kicad_pcb, SolarBox.kicad_sch]
2022-11-20 Fix headings and add PCB image
2022-11-21 More detailed documentation for Arduino. Upload examples for Arduino. Upload schematics and pictures for single charge controller examples. Fix incorrect index in python version. Fix incorrect regist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
    [Single-Arduino-Nano.kicad_sch, Single-ESP8266.kicad_sch, SolarBox.kicad_pcb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]
2022-12-24 - switch cc address to 255 - add instructions for how to modify the modbus library to handle 255 - fix bug in my current setup where if mqtt server died LCD would refresh slowly since MQTT kept tryin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
    [SOLAR_RECEIVE.ino, SOLAR_SEND_CC1.ino, SOLAR_SEND_CC2.ino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]
2022-12-24 add request delay jitter to my current setup
    [SOLAR_SEND_CC1.ino, SOLAR_SEND_CC2.ino, SOLAR_SEND_CC3.ino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]
2022-12-24 - fix inconsistencies in formatting between files - update readme files
    [SOLAR_RECEIVE.ino, SOLAR_SEND_CC1.ino, SOLAR_SEND_CC2.ino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]
2023-04-23 Add v2,1 (ESP32). Still need to do testing of some changes.
    [ESP32_SolarBox.kicad_pcb, ESP32_SolarBox.kicad_sch]
2023-04-23 fix spelling and readmes.
    [ESP32-Example.ino]
2023-04-28 - Add web interfaces. - Remove old arduino stuff. - Move stuff around to make it easier to navigate. - Fix problem with python version that didn't let it run at all. - Add MQTT example programs (unte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
    [ESP32_SolarBox.kicad_pcb, ESP32_SolarBox.kicad_sch, Single-Arduino-Nano.kicad_sch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]
2023-05-06 Fix modal X button not unlocking plug.
